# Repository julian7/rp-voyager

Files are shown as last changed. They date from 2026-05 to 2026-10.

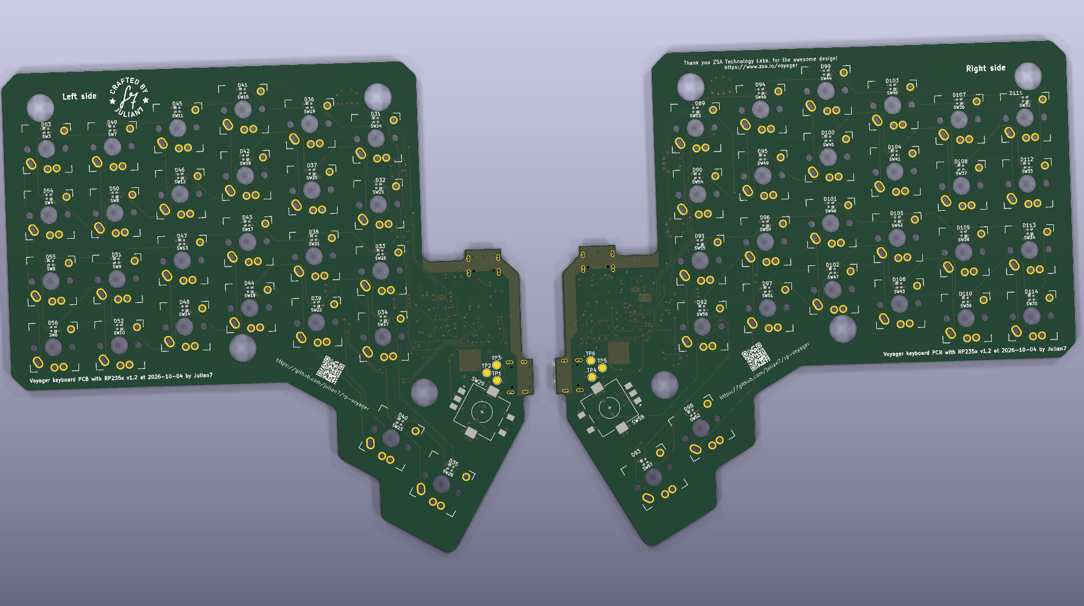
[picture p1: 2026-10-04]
docs/board-front.jpg

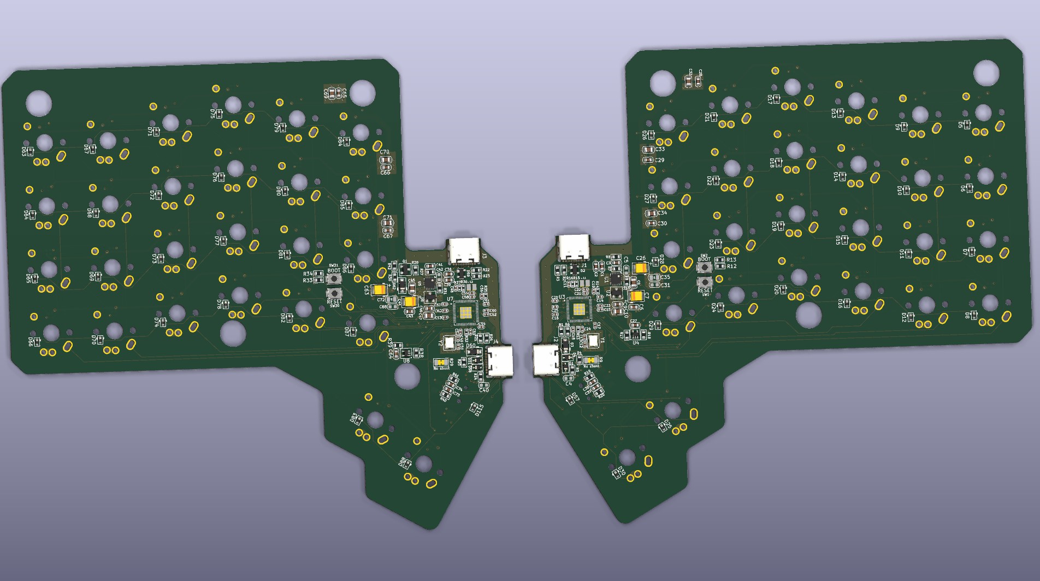
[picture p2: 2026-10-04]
docs/board-back.jpg

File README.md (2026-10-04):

# Voyager keyboard with RP2354A

This repository contains the necessary files for manufacturing of a split keyboard with on-board RP2354A microcontroller.

Features:

- On-board RP2354A MCU (2MB flash) for each side
- USB-C connection for power, firmware update, and a separate USB-C for UART connection between the halves
- RGB matrix under each key
- Gateron KS-33 / Kailh Choc v1 / Kailh Choc v2 low-profile keyswitches
- 1.2mm top plate (mainly planning for KS-33)

Non-features:

- Wireless functionality
- No tooling for mass production beyond common PCB houses and hobbyist CNC/3D print.

## What is Voyager?

Voyager is a minimal, split keyboard by [ZSA Technology Labs](https://www.zsa.io/), the same company who was behind the now discontinued Planck EZ.

The original Voyager is using an STM32 MCU, with RGB matrix. It has 52 keys, and 52 LEDs.

## Project status

Version v1.0 has been built, but the left side is not usable:

- ROW0-ROW3 are not connected to the MCU
- missing trace between CONN_TX test pad and the side USB recepticle's TX line

The right side can be put to work, with a single design flaw:

- The eFuse is always disabled. As a solution, put a 1 MΩ resistor (I've used a 0805 package, but probably a 0603 would be better) between pin 1 and pin 2 of Q1 MOSFET.

In general, LED silk screen markings were unreadable, and the ones I've purchased had different pin numbering. I've placed them by following the traces instead.

As a minor detail, SMD encoders' holes are a bit too tight, a 0.1mm clearance is added. Some silkscreen markings were adjusted for readability and visibility.

Version v1.1: only left side has been ordered, as there are no significant upgrades on the right side.

Version v1.2 (PCB only): hours after ordering the PCB I found that the keyboard layout is slightly different on the right side. Since I've ordered a new series of the left half, I've updated the design for the right one. A mechanical plate design now contains a v1-specific right plate.

## Can I copy it?

I don't recommend any usage at this point. Copyright-wise I retain all rights for now, probably opening up later. You can watch, you can learn, and you can laugh at my failures though.

The original design is originated by ZSA Technology Labs, Inc. I can't stop being gratituous enough for all the things they've done.

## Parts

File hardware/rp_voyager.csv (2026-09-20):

Reference | Qty | Value | DNP | Footprint | Distributor Link 1 | Distributor Link 2 | Distributor Link 3 | Description
R9,R29 | 2 | 0 | DNP | rp_voyager:R_1206_3216Metric_WireJumper |  |  |  | Resistor, small symbol
R10,R31 | 2 | 0 |  | PCM_Resistor_SMD_AKL:R_0603_1608Metric |  |  | https://www.hestore.hu/prod_10043634.html | Resistor, small symbol
C12,C13,C49,C50 | 4 | 15p |  | PCM_Capacitor_SMD_Handsoldering_AKL:C_0402_1005Metric |  |  |  | Unpolarized capacitor, small symbol
C5,C42 | 2 | 1n | DNP | PCM_Capacitor_SMD_Handsoldering_AKL:C_0603_1608Metric |  |  |  | Unpolarized capacitor, small symbol
C3,C41 | 2 | 10n |  | PCM_Capacitor_SMD_Handsoldering_AKL:C_0603_1608Metric |  |  | https://www.hestore.hu/prod_10027791.html | Unpolarized capacitor, small symbol
C4,C40 | 2 | 10n | DNP | PCM_Capacitor_SMD_Handsoldering_AKL:C_0603_1608Metric |  |  |  | Unpolarized capacitor, small symbol
C1,C6,C9,C27,C28,C29,C30,C36,C37,C38,C43,C46,C64,C65,C66,C67,C73,C74 | 18 | 100n |  | PCM_Capacitor_SMD_Handsoldering_AKL:C_0603_1608Metric |  |  | https://www.hestore.hu/prod_10033461.html | Unpolarized capacitor, small symbol
C11,C14,C15,C16,C17,C18,C20,C23,C25,C48,C51,C52,C53,C54,C55,C57,C60,C62 | 18 | 100n |  | PCM_Capacitor_SMD_Handsoldering_AKL:C_0402_1005Metric |  |  |  | Unpolarized capacitor, small symbol
C31,C68 | 2 | 100n | DNP | PCM_Capacitor_SMD_Handsoldering_AKL:C_0603_1608Metric |  |  |  | Unpolarized capacitor, small symbol
C19,C21,C22,C24,C56,C58,C59,C61 | 8 | 4.7u |  | PCM_Capacitor_SMD_Handsoldering_AKL:C_0402_1005Metric |  |  |  | Unpolarized capacitor, small symbol
C2,C39 | 2 | 10u |  | PCM_Capacitor_SMD_Handsoldering_AKL:C_0603_1608Metric |  |  | https://www.hestore.hu/prod_10043666.html | Unpolarized capacitor, small symbol
C8,C10,C32,C33,C34,C45,C47,C69,C70,C71 | 10 | 10u |  | PCM_Capacitor_SMD_Handsoldering_AKL:C_0805_2012Metric | https://hu.mouser.com/ProductDetail/KEMET/C0805C106M8RACAUTO7210?qs=HXFqYaX1Q2zcnWiZfdiXkQ%3D%3D |  |  | Poly
C35,C72 | 2 | 10u | DNP | PCM_Capacitor_SMD_Handsoldering_AKL:C_0805_2012Metric |  |  |  | Poly
C7,C26,C44,C63 | 4 | 220u |  | PCM_Capacitor_SMD_Handsoldering_AKL:C_1210_3225Metric | https://hu.mouser.com/ProductDetail/KYOCERA-AVX/TCJB227M006R0070 |  |  | 220uF 6.3V Polymer
R17,R38 | 2 | 22 |  | PCM_Resistor_SMD_AKL:R_0603_1608Metric |  |  | https://www.hestore.hu/prod_10023927.html | Resistor, small symbol
R15,R16,R36,R37 | 4 | 27 |  | PCM_Resistor_SMD_AKL:R_0402_1005Metric | https://hu.mouser.com/ProductDetail/YAGEO/RC0402FR-0727RL?qs=UOUeRUa%252B8Wlb37UyFHw9Bw%3D%3D |  |  | Resistor, small symbol
R14,R35 | 2 | 33 |  | PCM_Resistor_SMD_AKL:R_0402_1005Metric | https://hu.mouser.com/ProductDetail/YAGEO/RC0402FR-7D33RL |  |  | Resistor, small symbol
R18,R39 | 2 | 47 |  | PCM_Resistor_SMD_AKL:R_0603_1608Metric |  |  | https://www.hestore.hu/prod_10049205.html | Resistor, small symbol
R1,R6,R21,R26 | 4 | 220 |  | PCM_Resistor_SMD_AKL:R_0603_1608Metric |  |  | https://www.hestore.hu/prod_10036836.html | Resistor, small symbol
R11,R32 | 2 | 1k |  | PCM_Resistor_SMD_AKL:R_0402_1005Metric |  |  | https://www.hestore.hu/prod_10030528.html | Resistor, small symbol
R12,R13,R33,R34 | 4 | 1k |  | PCM_Resistor_SMD_AKL:R_0603_1608Metric |  |  | https://www.hestore.hu/prod_10049434.html | Resistor, small symbol
R2,R3,R4,R5,R22,R23,R24,R25 | 8 | 5.1k |  | PCM_Resistor_SMD_AKL:R_0603_1608Metric |  |  | https://www.hestore.hu/prod_10036539.html | Resistor, small symbol
R7,R19,R20,R27,R40,R41 | 6 | 10k |  | PCM_Resistor_SMD_AKL:R_0603_1608Metric |  |  | https://www.hestore.hu/prod_10023910.html | Resistor, small symbol
R8,R28,R30 | 3 | 100k |  | PCM_Resistor_SMD_AKL:R_0603_1608Metric |  |  | https://www.hestore.hu/prod_10043366.html | Resistor, small symbol
Y1,Y2 | 2 | 12MHz |  | PCM_Crystal_AKL:Crystal_SMD_3225-4Pin_3.2x2.5mm_HandSoldering | https://hu.mouser.com/ProductDetail/ABRACON/ABM8-272-T3?qs=QpmGXVUTftEj6miOiJBMxQ%3D%3D |  |  | ABM8-272-T3
D5,D6,D7,D8,D9,D10,D11,D12,D13,D14,D15,D16,D17,D18,D19,D20,D21,D22,D23,D24,D25,D26,D27,D28,D29,D30,D57,D63,D64,D65,D66,D67,D68,D69,D70,D71,D72,D73,D74,D75,D76,D77,D78,D79,D80,D81,D82,D83,D84,D85,D86,D87,D88,D115 | 54 | 1N4148WT |  | PCM_Diode_SMD_AKL:D_SOD-523 |  |  |  | Diode, small symbol
Q1 | 1 | 2N7002 |  | PCM_Package_TO_SOT_SMD_AKL:SOT-23 | https://hu.mouser.com/ProductDetail/Panjit/2N7002K_R1_00001?qs=sPbYRqrBIVmx5ZVZGJfwpA%3D%3D |  |  | SOT-23 N-MOSFET enchancement mode transistor, 60V, 380mA, 370mW, Alternate KiCAD Library
U4,U8 | 2 | 74HCT1G125GW |  | PCM_Package_TO_SOT_SMD_AKL:SOT-353_SC-70-5 | https://hu.mouser.com/ProductDetail/Nexperia/74HCT1G125GW125?qs=P62ublwmbi9fxWhuHktl8w%3D%3D |  |  | Single Buffer Gate Tri-State, Low-Voltage CMOS
L1,L2 | 2 | AOTA-B201610S3R3-101-T |  | rp_voyager:INDC2016X100N | https://hu.mouser.com/ProductDetail/815-AB201610S3R3101T |  |  | Power Inductors - SMD IND 3.3uH
U2,U6 | 2 | AP2125N-3.3TRG1 |  | PCM_Package_TO_SOT_SMD_AKL:SOT-23 | https://hu.mouser.com/ProductDetail/Diodes-Incorporated/AP2125N-3.3TRG1?qs=x6A8l6qLYDCwcNnV9UPDXg%3D%3D |  |  | SOT-23 3.3V 300mA low dropout voltage regulator, Alternate KiCad Library
D62 | 1 | B0520LW-7-F |  | PCM_Diode_SMD_Handsoldering_AKL:D_SOD-123 | https://hu.mouser.com/ProductDetail/Diodes-Incorporated/B0520LW-7-F?qs=ohlXZ7HLwzhBk0UMEtqL4A%3D%3D
SW2,SW31 | 2 | BOOTSEL |  | Button_Switch_SMD:SW_Push_SPST_NO_Alps_SKRK |  |  |  | Push button switch, generic, two pins
D1,D4,D58,D61 | 4 | DESD5V0U1BA-7 |  | PCM_Diode_SMD_Handsoldering_AKL:D_SOD-323_TVS | https://hu.mouser.com/ProductDetail/Diodes-Incorporated/DESD5V0U1BA-7?qs=wtVJq%252Be05r98RUWcs2LyvQ%3D%3D |  |  | Bidirectional TVS Diode, Generic symbol, Alternate KiCAD Library
TP3,TP6 | 2 | I2C 5V |  | TestPoint:TestPoint_Pad_D2.0mm |  |  |  | test point
J1,J3 | 2 | INPUT USB |  | Connector_USB:USB_C_Receptacle_GCT_USB4105-xx-A_16P_TopMnt_Horizontal |  |  |  | USB 2.0-only 14P Type-C Receptacle connector
SW3,SW4,SW5,SW6,SW7,SW8,SW9,SW10,SW11,SW12,SW13,SW14,SW15,SW16,SW17,SW18,SW19,SW20,SW21,SW22,SW23,SW24,SW25,SW26,SW27,SW32,SW33,SW34,SW35,SW36,SW37,SW38,SW39,SW40,SW41,SW42,SW43,SW44,SW45,SW46,SW47,SW48,SW49,SW50,SW51,SW52,SW53,SW54,SW55,SW56 | 50 | Key |  | rp_voyager:Gateron-KS33-Solderable-1U |  |  |  | Push button switch, normally open, two pins, 45Ã Â° tilted
SW28,SW57 | 2 | Key |  | rp_voyager:Gateron-KS33-Solderable-1x1.5U |  |  |  | Push button switch, normally open, two pins, 45Ã Â° tilted
D2,D59 | 2 | PRTR5V0U2X |  | Package_TO_SOT_SMD:SOT-143 | https://hu.mouser.com/ProductDetail/Nexperia/PRTR5V0U2X215?qs=LOCUfHb8d9sDkgY4cRj8Lw%3D%3D |  |  | Ultra low capacitance double rail-to-rail ESD protection diode, SOT-143
SW1,SW30 | 2 | RESET |  | Button_Switch_SMD:SW_Push_SPST_NO_Alps_SKRK |  |  |  | Push button switch, generic, two pins
SW29,SW58 | 2 | RotaryEncoder_Switch_MP |  | rp_voyager:RotaryEncoder_Alps_EC11S-Switch_Vertical_H9mm |  |  |  | Rotary encoder, dual channel, incremental quadrate outputs, with switch and MP Pin
U3,U7 | 2 | RP2354A |  | Package_DFN_QFN:QFN-60-1EP_7x7mm_P0.4mm_EP3.4x3.4mm |  |  |  | A microcontroller by Raspberry Pi, dual CPU architecture (ARM Cortex-M33 / RISC-V Hazard3), 150MHz, 2MB flash, 520KB SRAM, 12 PIO state machines, VQFN-60
D31,D32,D33,D34,D35,D36,D37,D38,D39,D40,D41,D42,D43,D44,D45,D46,D47,D48,D49,D50,D51,D52,D53,D54,D55,D56,D89,D90,D91,D92,D93,D94,D95,D96,D97,D98,D99,D100,D101,D102,D103,D104,D105,D106,D107,D108,D109,D110,D111,D112,D113,D114 | 52 | SK6812 EC20 |  | rp_voyager:LED_SK6812_EC20_2x2mm |  |  |  | RGB LED with integrated controller, 2.0 x 2.0 mm, 12 mA
D3,D60 | 2 | SZSMF5.0AT1G |  | PCM_Diode_SMD_Handsoldering_AKL:D_SOD-123_Zener | https://hu.mouser.com/ProductDetail/Littelfuse/SZSMF5.0AT1G?qs=sK5eIuwOod5l2VwwT9yiGQ%3D%3D |  |  | Unidirectional TVS diode, Generic symbol, Alternate KiCAD Library
U1,U5 | 2 | TPS259261 |  | Package_SON:VSON-10-1EP_3x3mm_P0.5mm_EP1.65x2.4mm_ThermalVias | https://hu.mouser.com/ProductDetail/Texas-Instruments/TPS259261DRCR?qs=rBWM4%252BvDhIfYkNEYPOLMtQ%3D%3D | https://www.digikey.hu/hu/products/detail/texas-instruments/tps259261drcr/5481852 |  | 5V/12V eFuse Protection Switch (VSON-10)
J2,J4 | 2 | UART USB |  | Connector_USB:USB_C_Receptacle_GCT_USB4105-xx-A_16P_TopMnt_Horizontal |  |  |  | USB 2.0-only 14P Type-C Receptacle connector
TP2,TP5 | 2 | UART_RX |  | TestPoint:TestPoint_Pad_D2.0mm |  |  |  | test point
TP1,TP4 | 2 | UART_TX |  | TestPoint:TestPoint_Pad_D2.0mm |  |  |  | test point

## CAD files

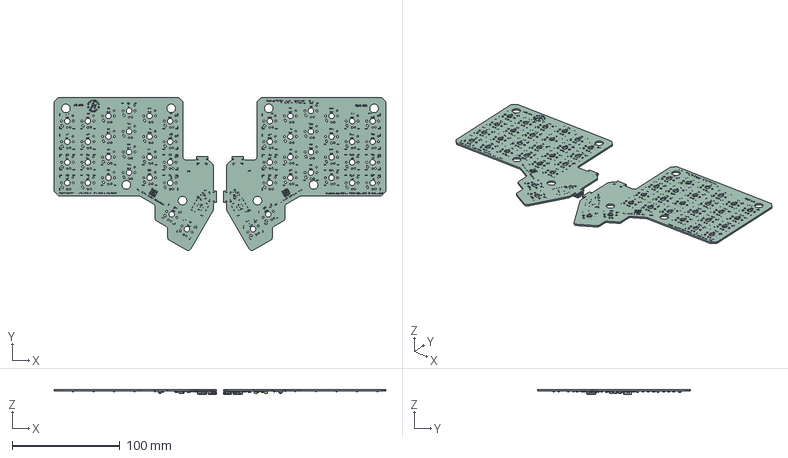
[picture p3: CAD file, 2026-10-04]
mechanical/board_v12.step
307.5 x 141.7 x 4.98 mm
C_0402_1005Metric x 30
D_SOD-123 x 3
D_SOD_523 x 54
D_SOD-323 x 4
CP_EIA_3528_21_Kemet_B x 4
R_0603_1608Metric x 32
C_0603_1608Metric x 28
SOT-23 x 3
R_0402_1005Metric x 8
SOT-353_SC-70-5 x 2
C_0805_2012Metric x 12
SW_Push_SPST_NO_Alps_SKRK x 4
R_1206_3216Metric x 2
USB_C_Receptacle_16P_TopMnt_Horizontal_GCT_USB4105-xx-A x 4
SOT-143 x 2
VSON_10_1EP_3x3mm_Pitch05mm_ThermalPad x 2
Crystal_SMD_Abracon_ABM8G-4Pin_3.2x2.5mm x 2
rp_voyager_silkscreen x 2
rp_voyager_PCB_1
rp_voyager_PCB_2

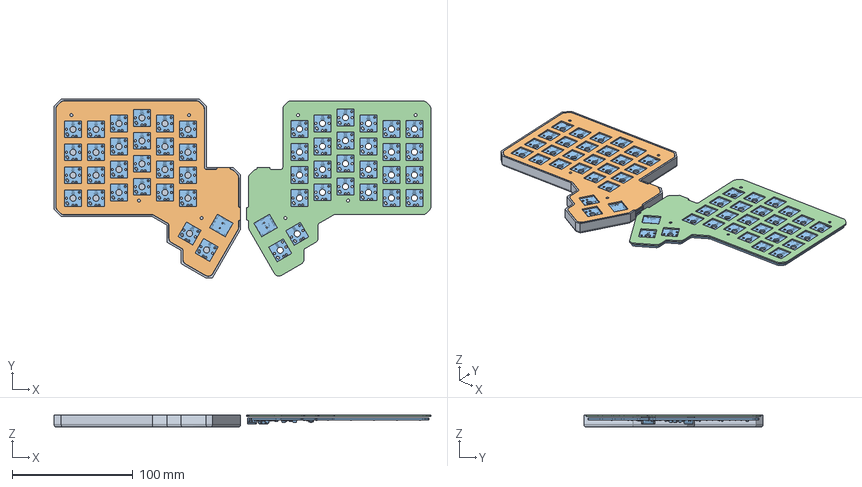
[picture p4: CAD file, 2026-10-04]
mechanical/rp-voyager.FCStd
312.6 x 148.7 x 10.1 mm
tray
plate
board_v1.1
plate-right-v1

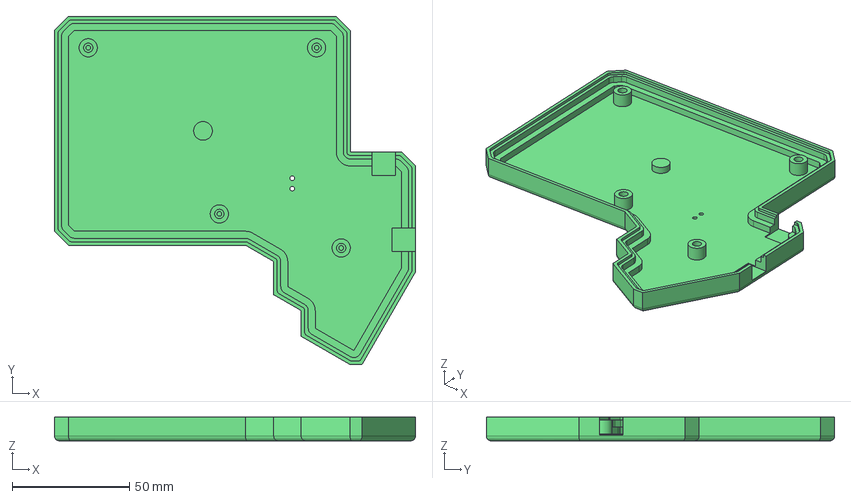
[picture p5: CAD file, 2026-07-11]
mechanical/rp-voyager-tray.step
154.1 x 148.7 x 10.1 mm

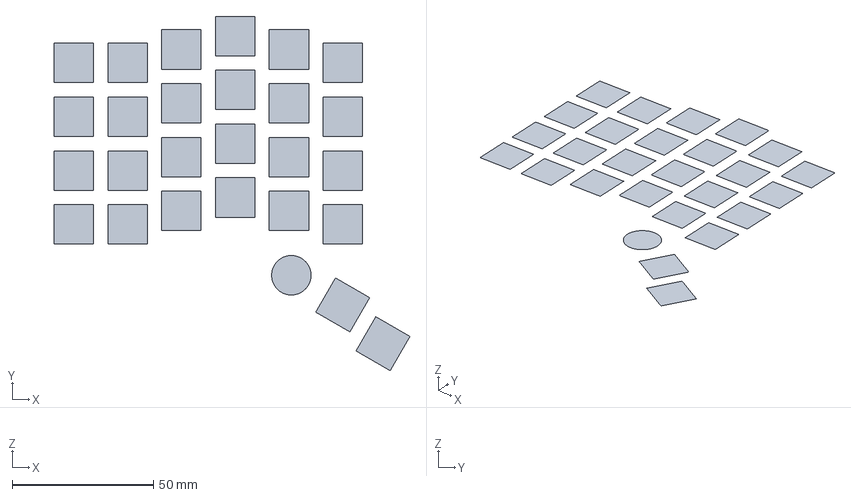
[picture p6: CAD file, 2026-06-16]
mechanical/layout.FCStd
126.0 x 125.5 x 0 mm

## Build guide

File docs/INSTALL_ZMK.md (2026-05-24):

# ZMK firmware for RP-Voyager

## Install native ZMK toolchain

```shell
brew install uv cmake ninja gperf python3 python-tk ccache qemu dtc libmagic wget openocd
uv tool install west
git clone https://github.com/zmkfirmware/zmk.git ~/src/zmk
cd zmk
uv init --bare
uv add west pip
uv run west init -l app/
uv run west update
uv run west zephyr-export
uv run west packages pip --install
uv run west sdk install -t arm-zephyr-eabi
```

## Specifics

The previous snippet assumes MacOS with Homebrew. Follow [Native local toolchain setup](https://zmk.dev/docs/development/local-toolchain/setup/native) guide for your operating system.

It also depends on `uv` so that the environment can be localized into `~/src/zmk`. You'll have to initiate builds from that directory.

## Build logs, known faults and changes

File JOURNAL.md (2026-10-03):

# Journal

The local supplier doesn't have everything in stock, so I ordered the main components from Mouser. I've ordered some of the components from Aliexpress.

I've made the first release, tagged as v1.0. I've ordered 5 prototype boards from JLCPCB, with stencils.  All the components arrived. The stencil made the PCB ordering way harder, as it was held back at customs for a week, as it was missing sanction declaration.

I've placed the bottom components of the left side, with some findings:

- The bulk cap (220 µF) has a 6.3V rating, which might be a bit problematic on the 5V rail. I've replaced that with a 10V-rated one, but I decided it will still do some good work on the LED circuit.
- Markings for the poly bulk cap is unipolar, but it is a polarized capacitor. It also caused a short, as it was placed anode side to GND.
- The crystal is taking a huge chunk of real estate, that could be smaller.
- Minor nuissance, ROW0-ROW3 are not connected to the MCU, leaving the majority of the keys unusable on the left side.
- There is a missing trace between CONN_TX test pad and the side USB recepticle's TX line in the design. For some reason, they are connected on the board I've received.

I now continue with some LEDs and making a right side, so that I can find more issues before placing a second order for PCBs.

---

Sep 30

I've built a right side, only bottom side. The board has some issues with the eFuse's EN signal. The board takes 0.037A if Q1 is off the board, that's a normal power consumption with no LEDs. Probably, Q1 gate needs a 1M pulldown resistor.

I want to test all three power scenarios on the right side: main only, side only, both. I'll use the PSU on main for the third scenario, I should measure 0A.

---

Oct 2

The right half started working well once I've installed a 1MΩ resistor between Q1's pin 1 and 2. The eFuse is disabled consistently when power also comes from UART USB.

I've installed a few LEDs, but they don't seem to be driven. The left side had a LED lighting bright blue for a moment, but it lasted only a second. I'll have to go back to the backlight once the more fundamental questions are solved.

I've updated the filler GPIO layouts, so that they are correctly connected. The keyboard matrix had some surprises too, as the right side's colums have been wired right to left. Apart from that, the right side is functioning well.

~~Apparently, sometimes the LEDs are working "somewhat", probably the first LEDs are broken but not completely dead.~~

Apparently, only one LED is burnt, the others had soldering issues.

---

Oct 3

Finished building the right side. All LEDs, all hotswap sockets, and the encoder works well through the UART connection from the left side.

At the same time, the first LED works on the left side, so we can conclude that only the left side PCB needs an update, the right one can be fixed with a 0603 resistor soldered on Q1's pins 1-2.

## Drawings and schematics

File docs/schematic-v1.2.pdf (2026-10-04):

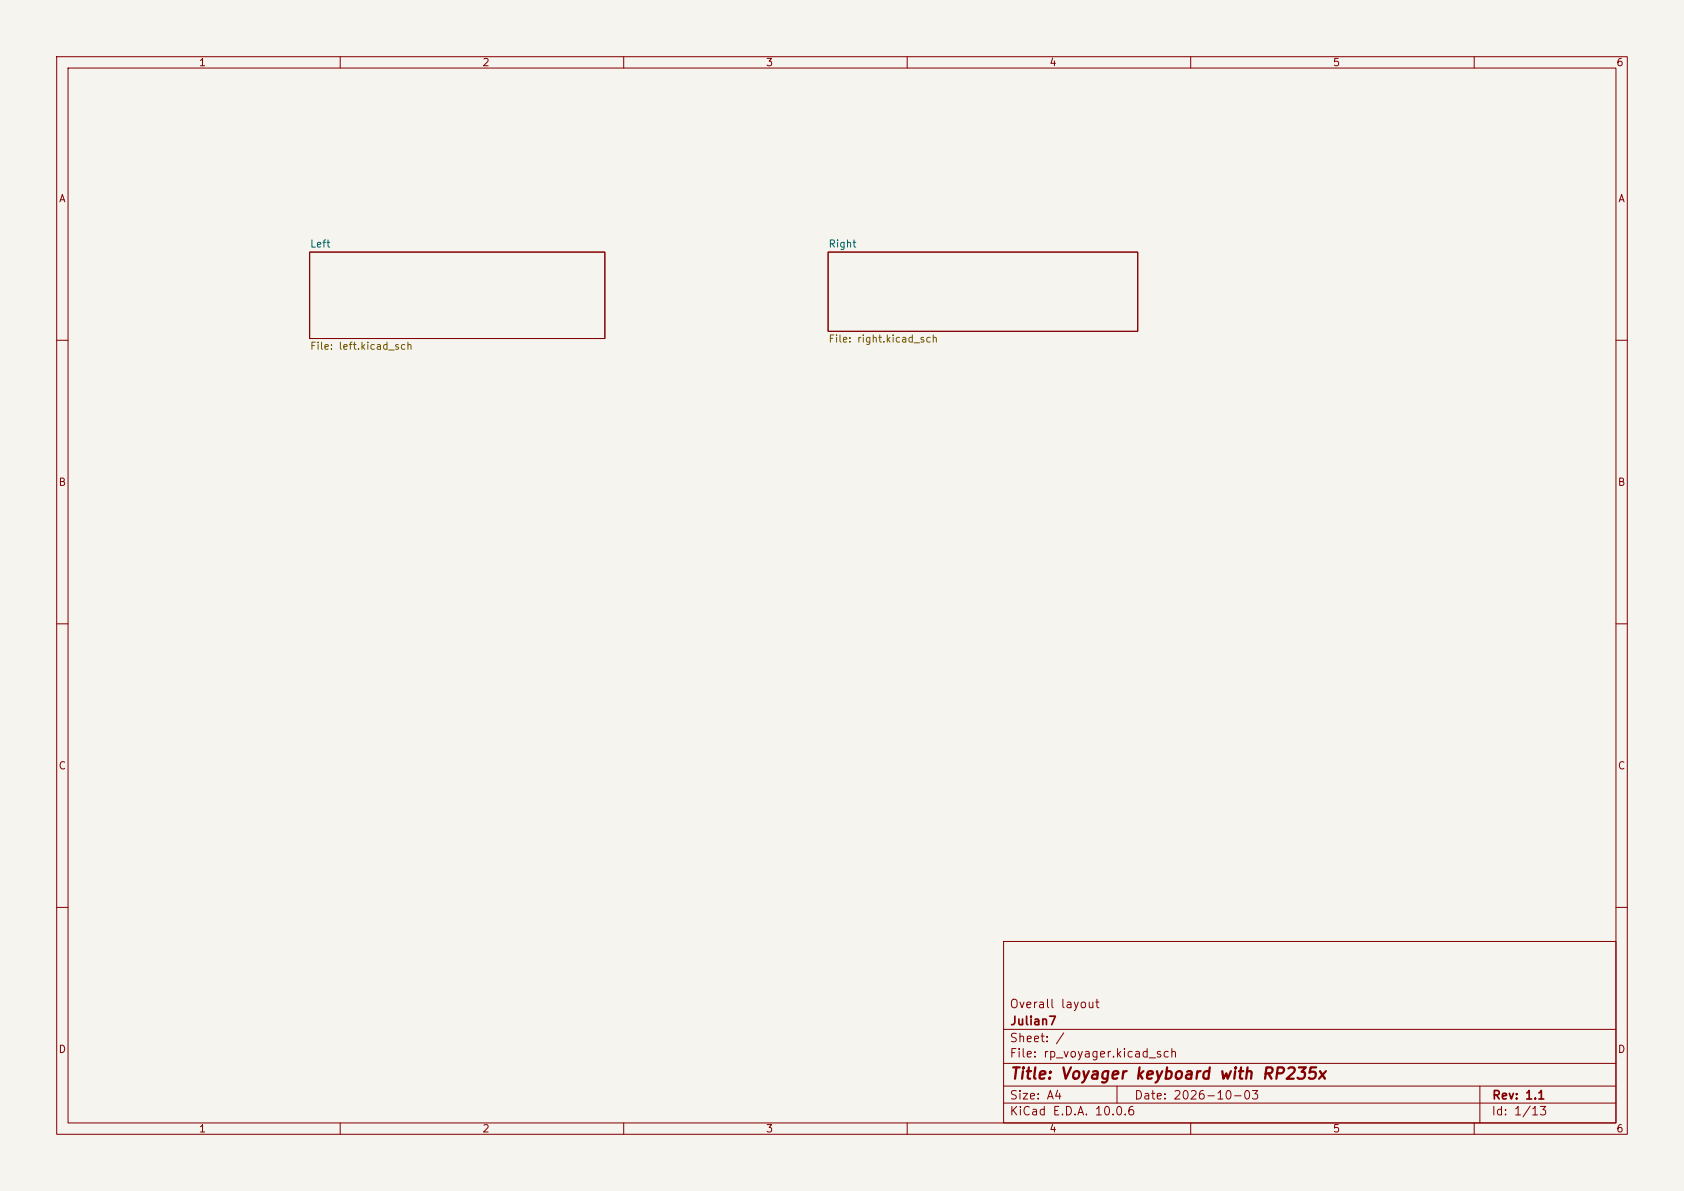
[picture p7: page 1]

Size: A4 | Rev: 1.1
KiCad E.D.A. 10.0.6 | Id: 1/13

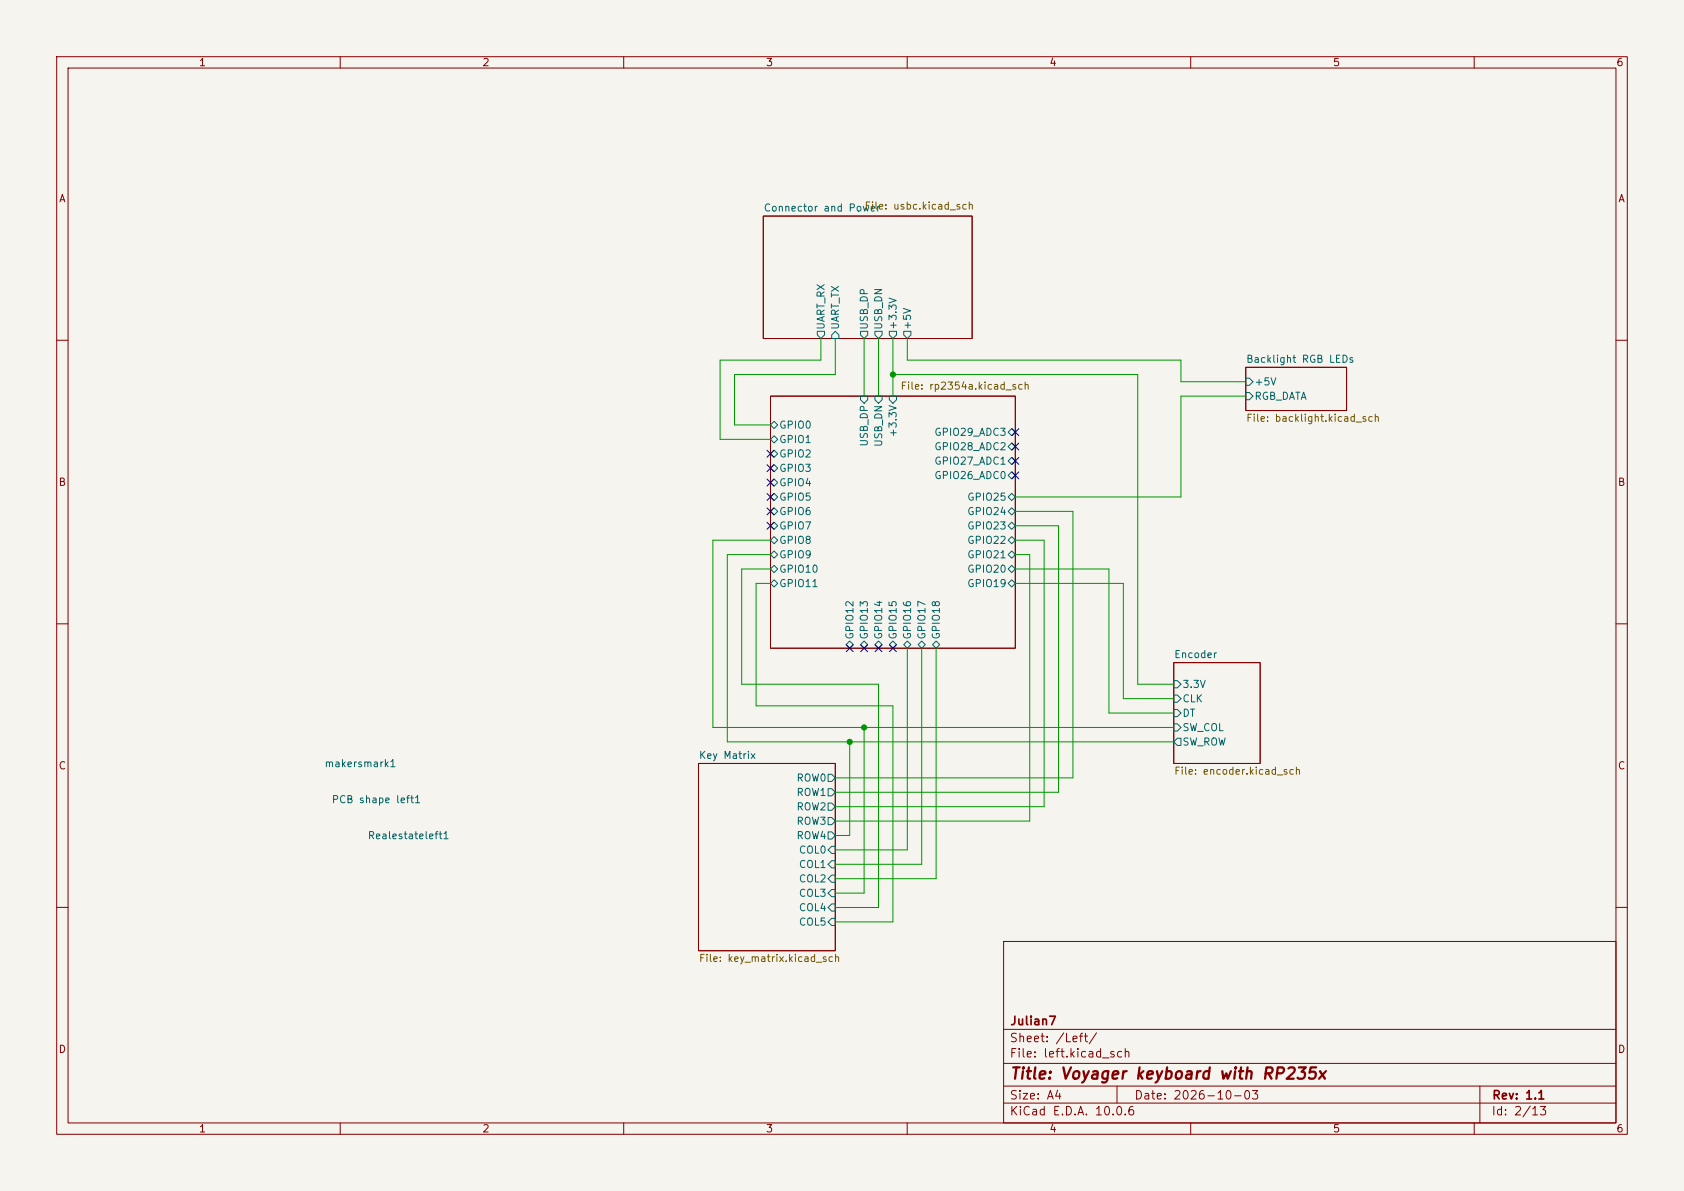
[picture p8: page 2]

Julian7
Sheet: /Left/
File: left.kicad_sch
Title: Voyager keyboard with RP235x

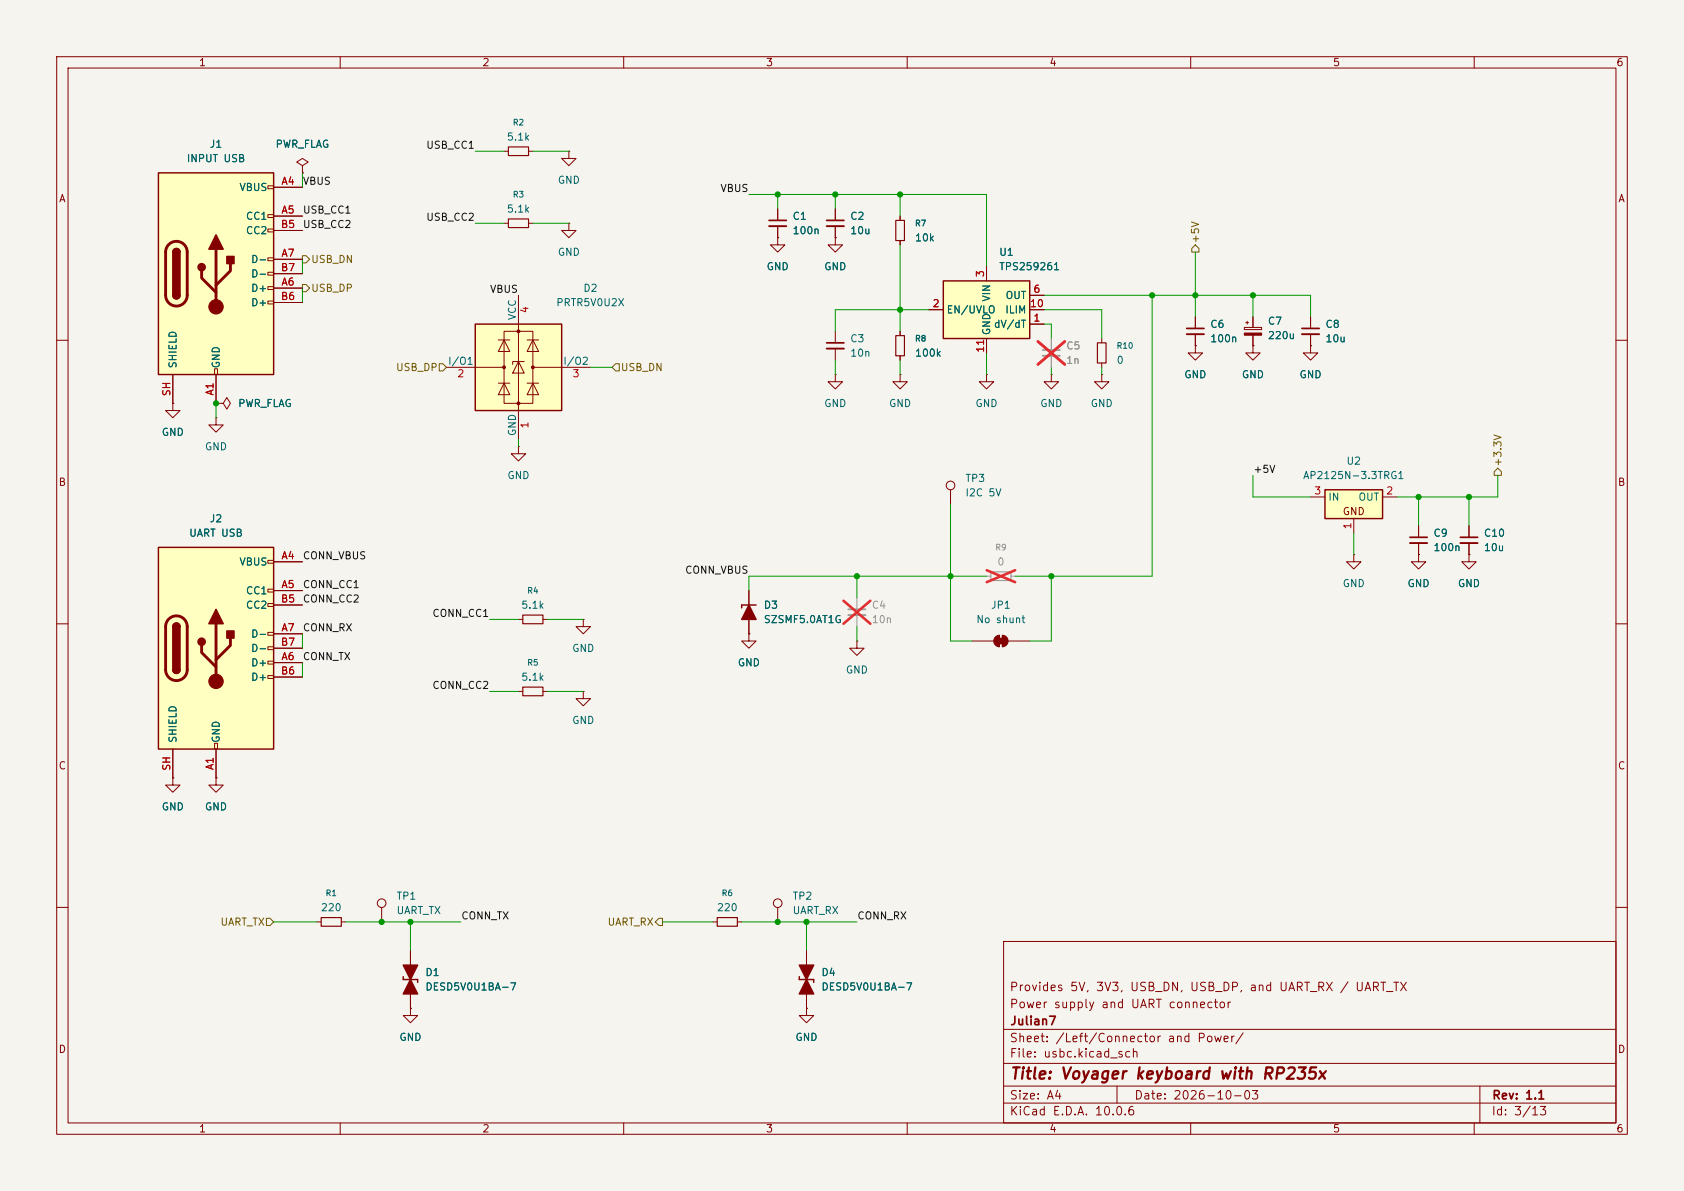
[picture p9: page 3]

Provides 5V, 3V3, USB_DN, USB_DP, and UART_RX / UART_TX
Power supply and UART connector
Julian7
Sheet: /Left/Connector and Power/
File: usbc.kicad_sch
Title: Voyager keyboard with RP235x

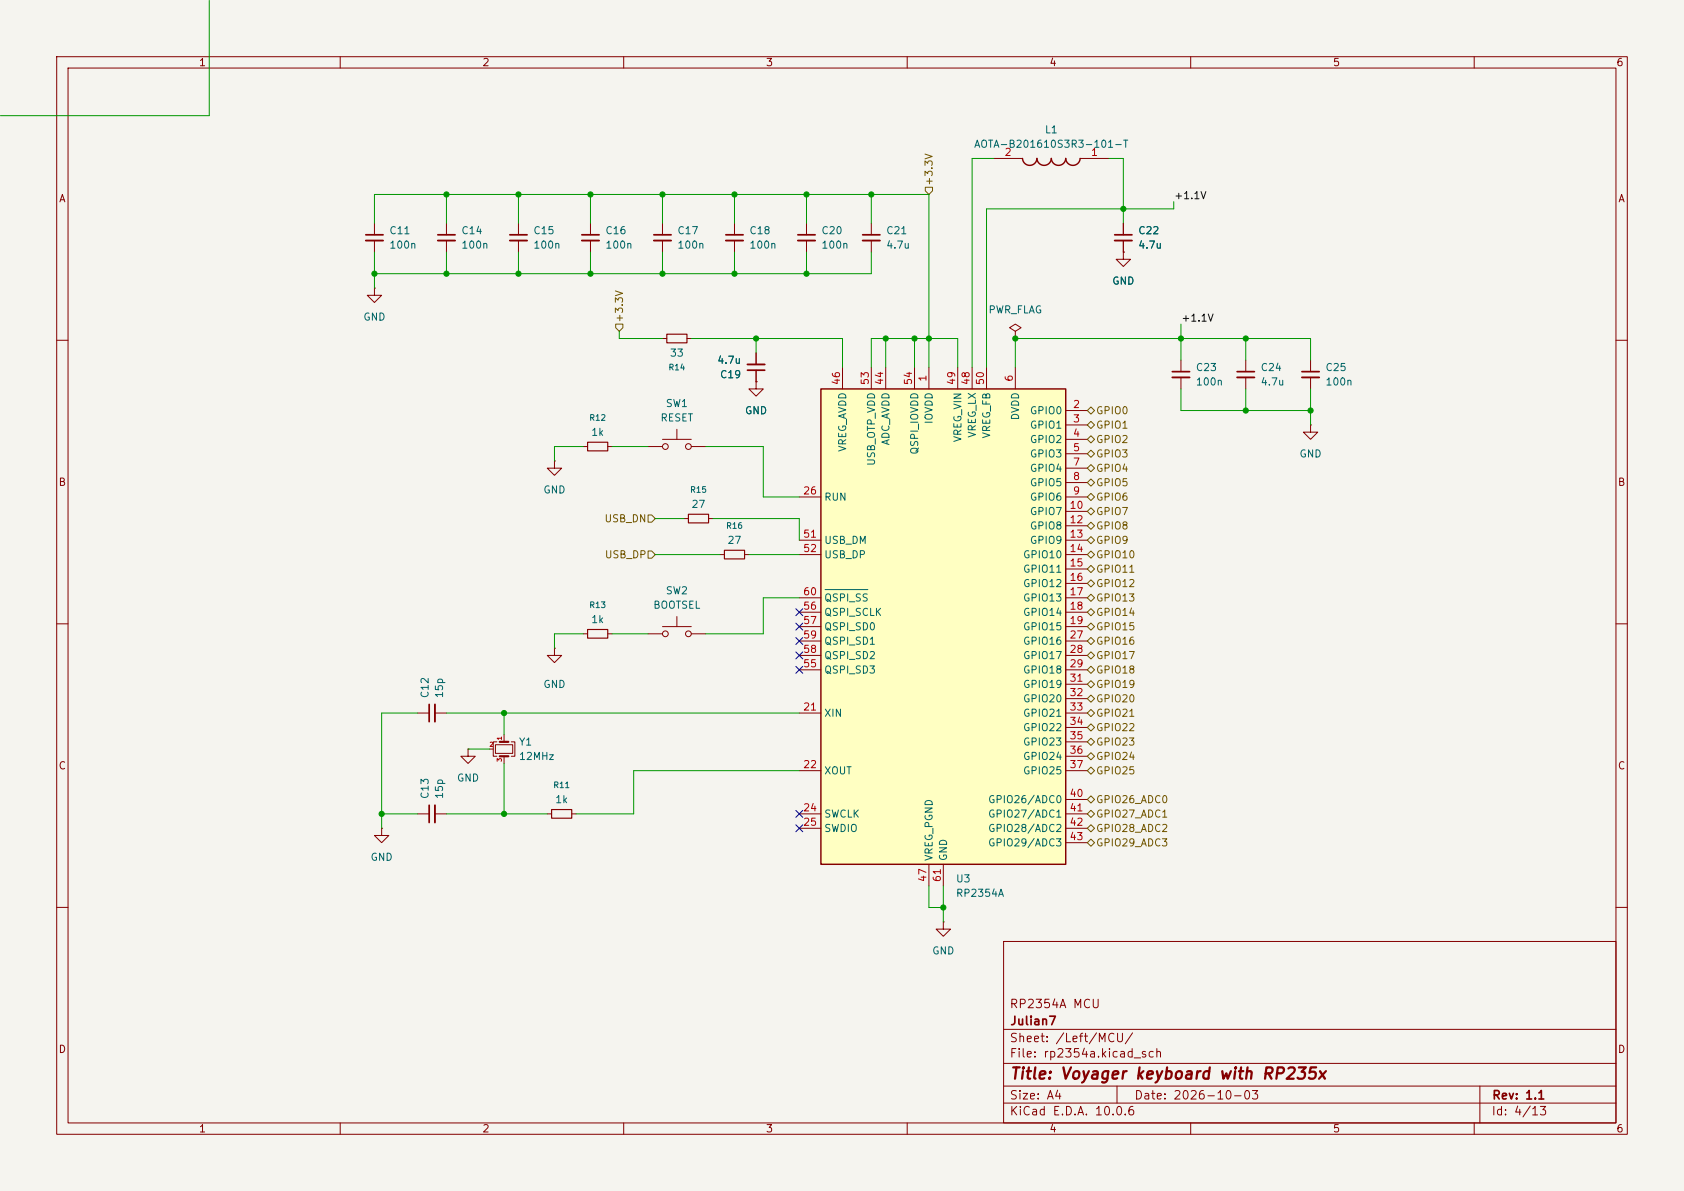
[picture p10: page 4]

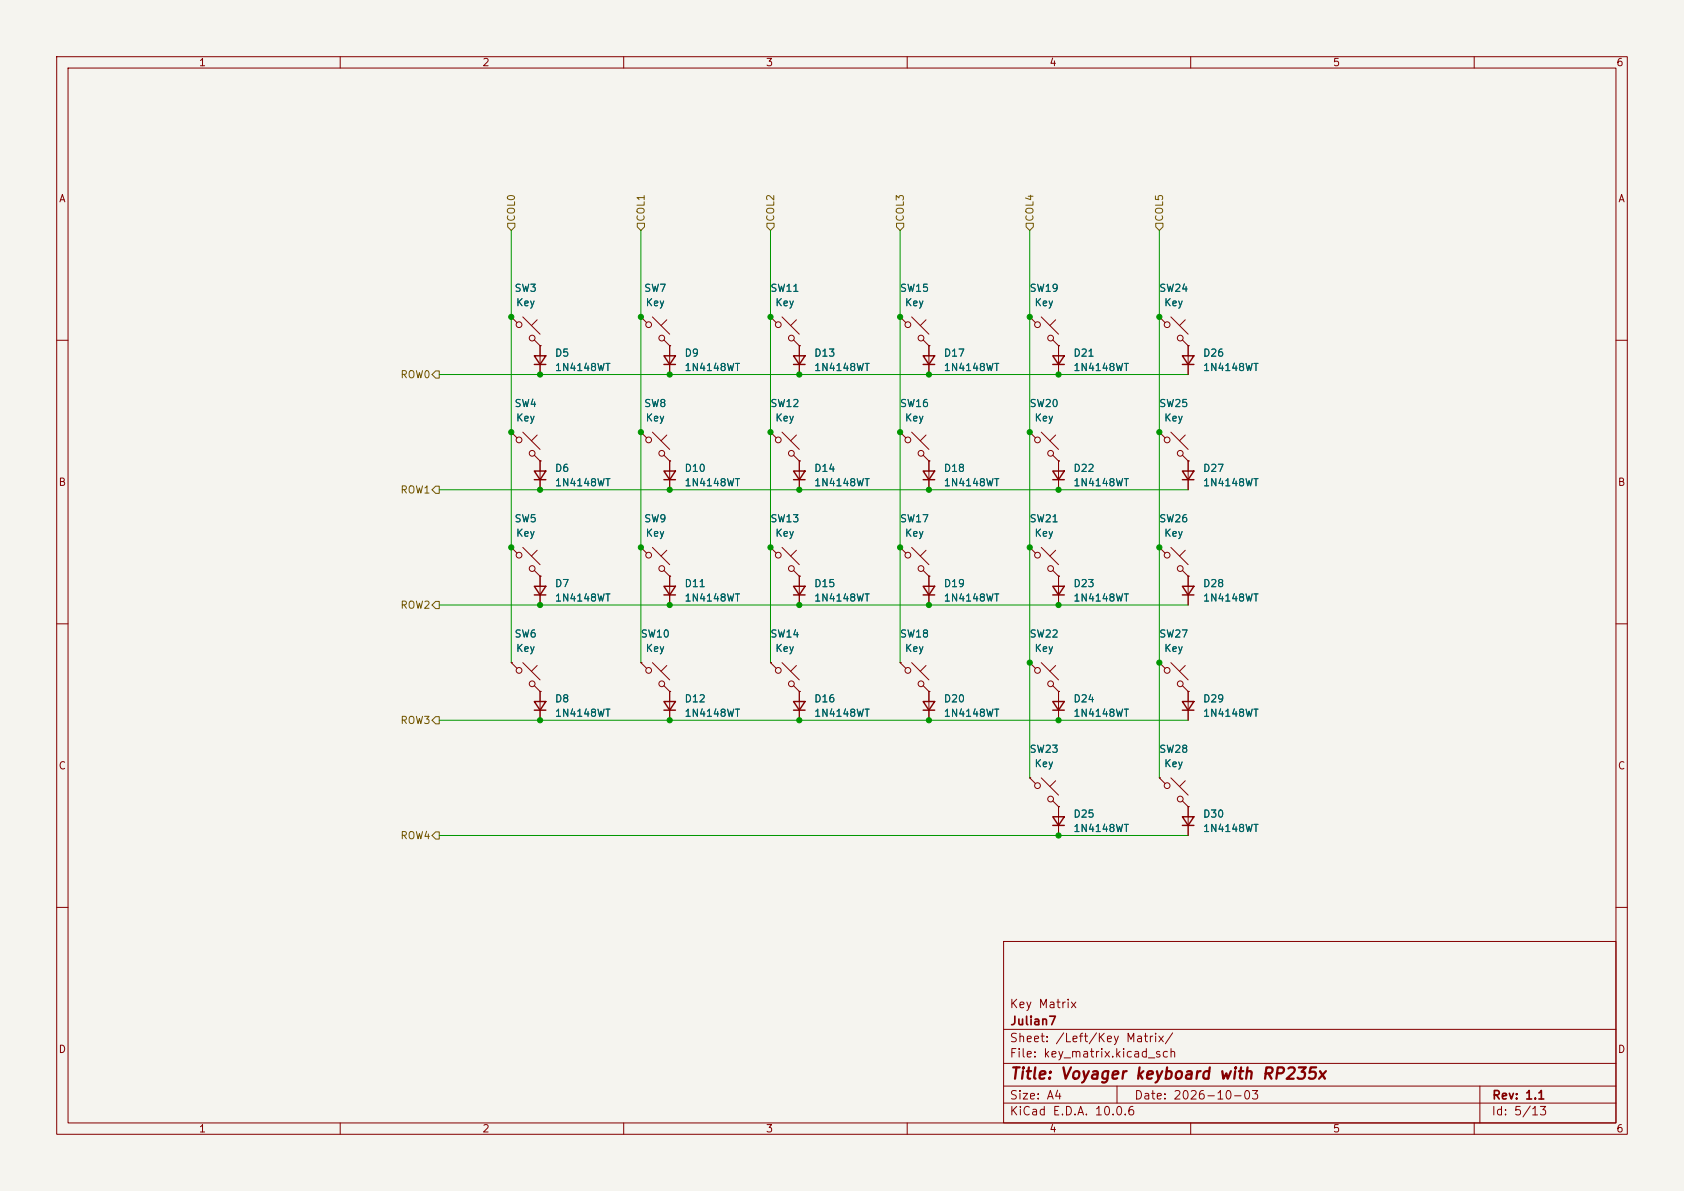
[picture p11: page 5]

Key Matrix
Julian7
Sheet: /Left/Key Matrix/
File: key_matrix.kicad_sch
Title: Voyager keyboard with RP235x

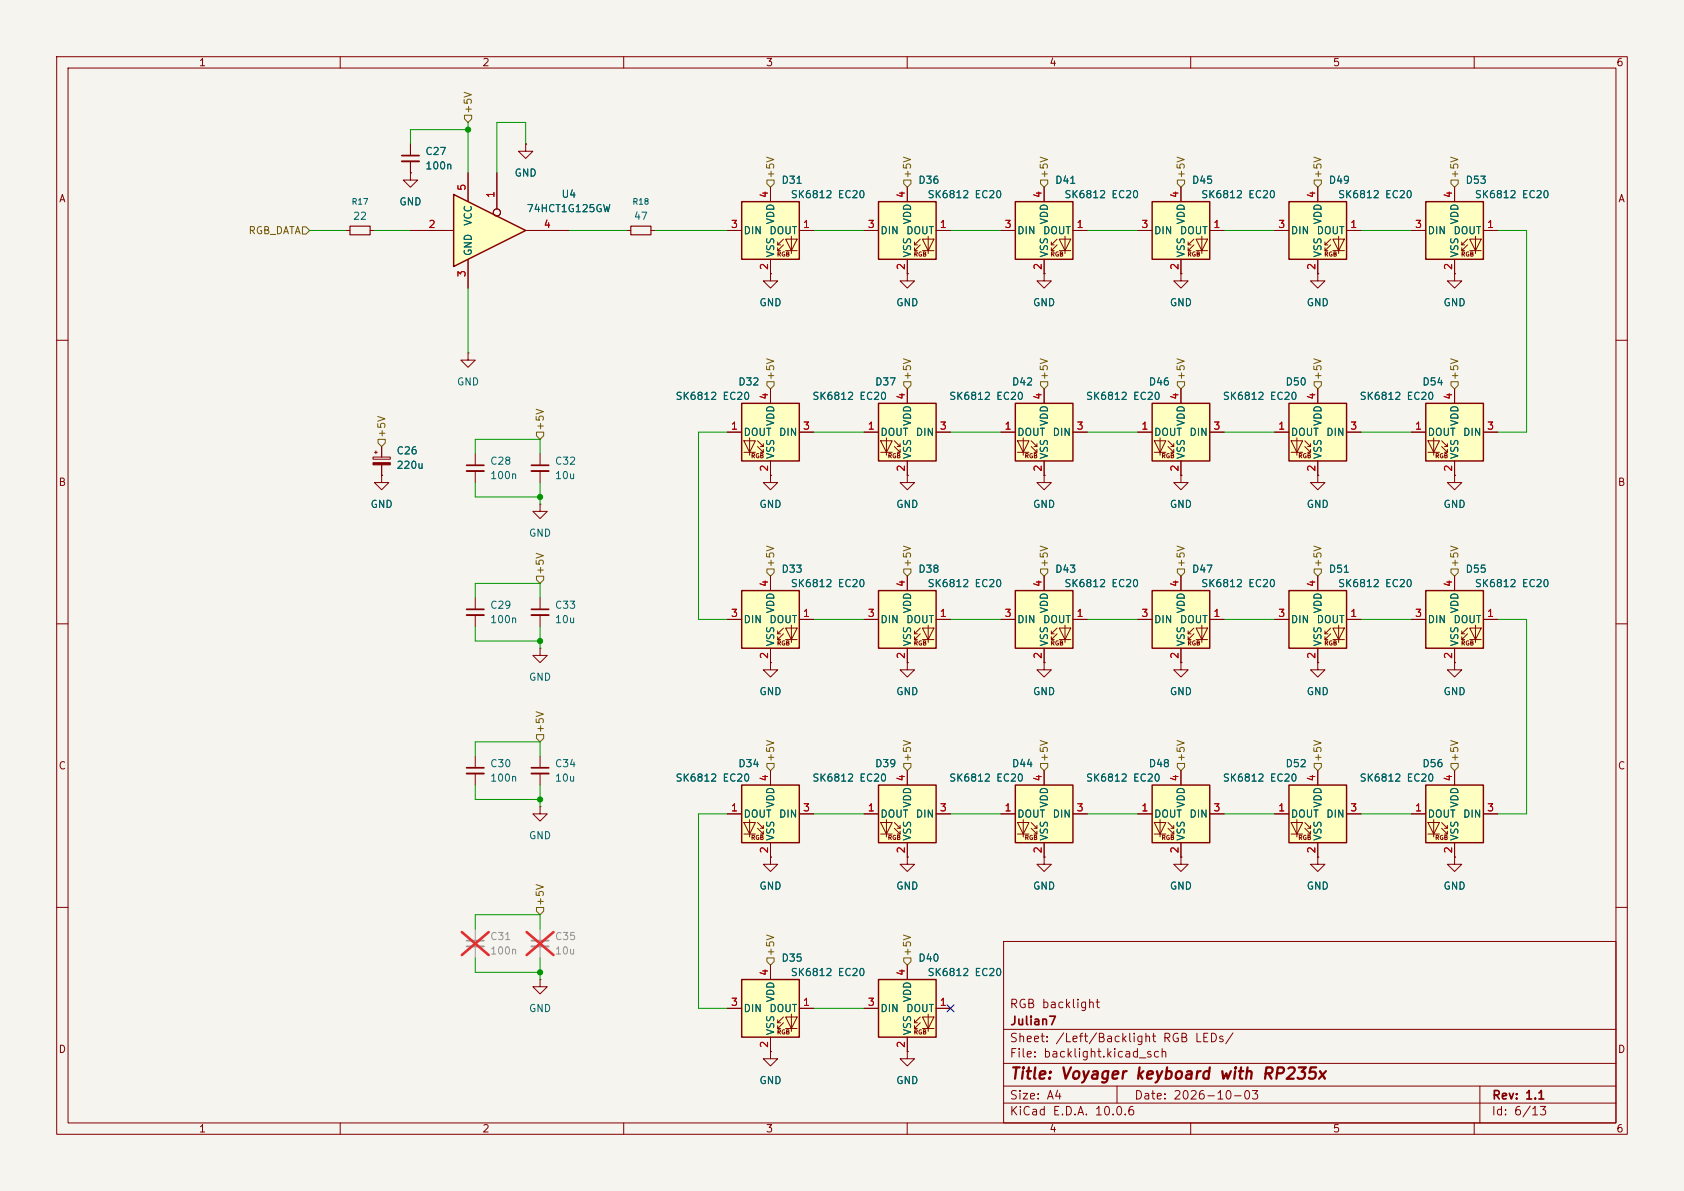
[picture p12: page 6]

Julian7
Sheet: /Left/Backlight RGB LEDs/
File: backlight.kicad_sch
Title: Voyager keyboard with RP235x

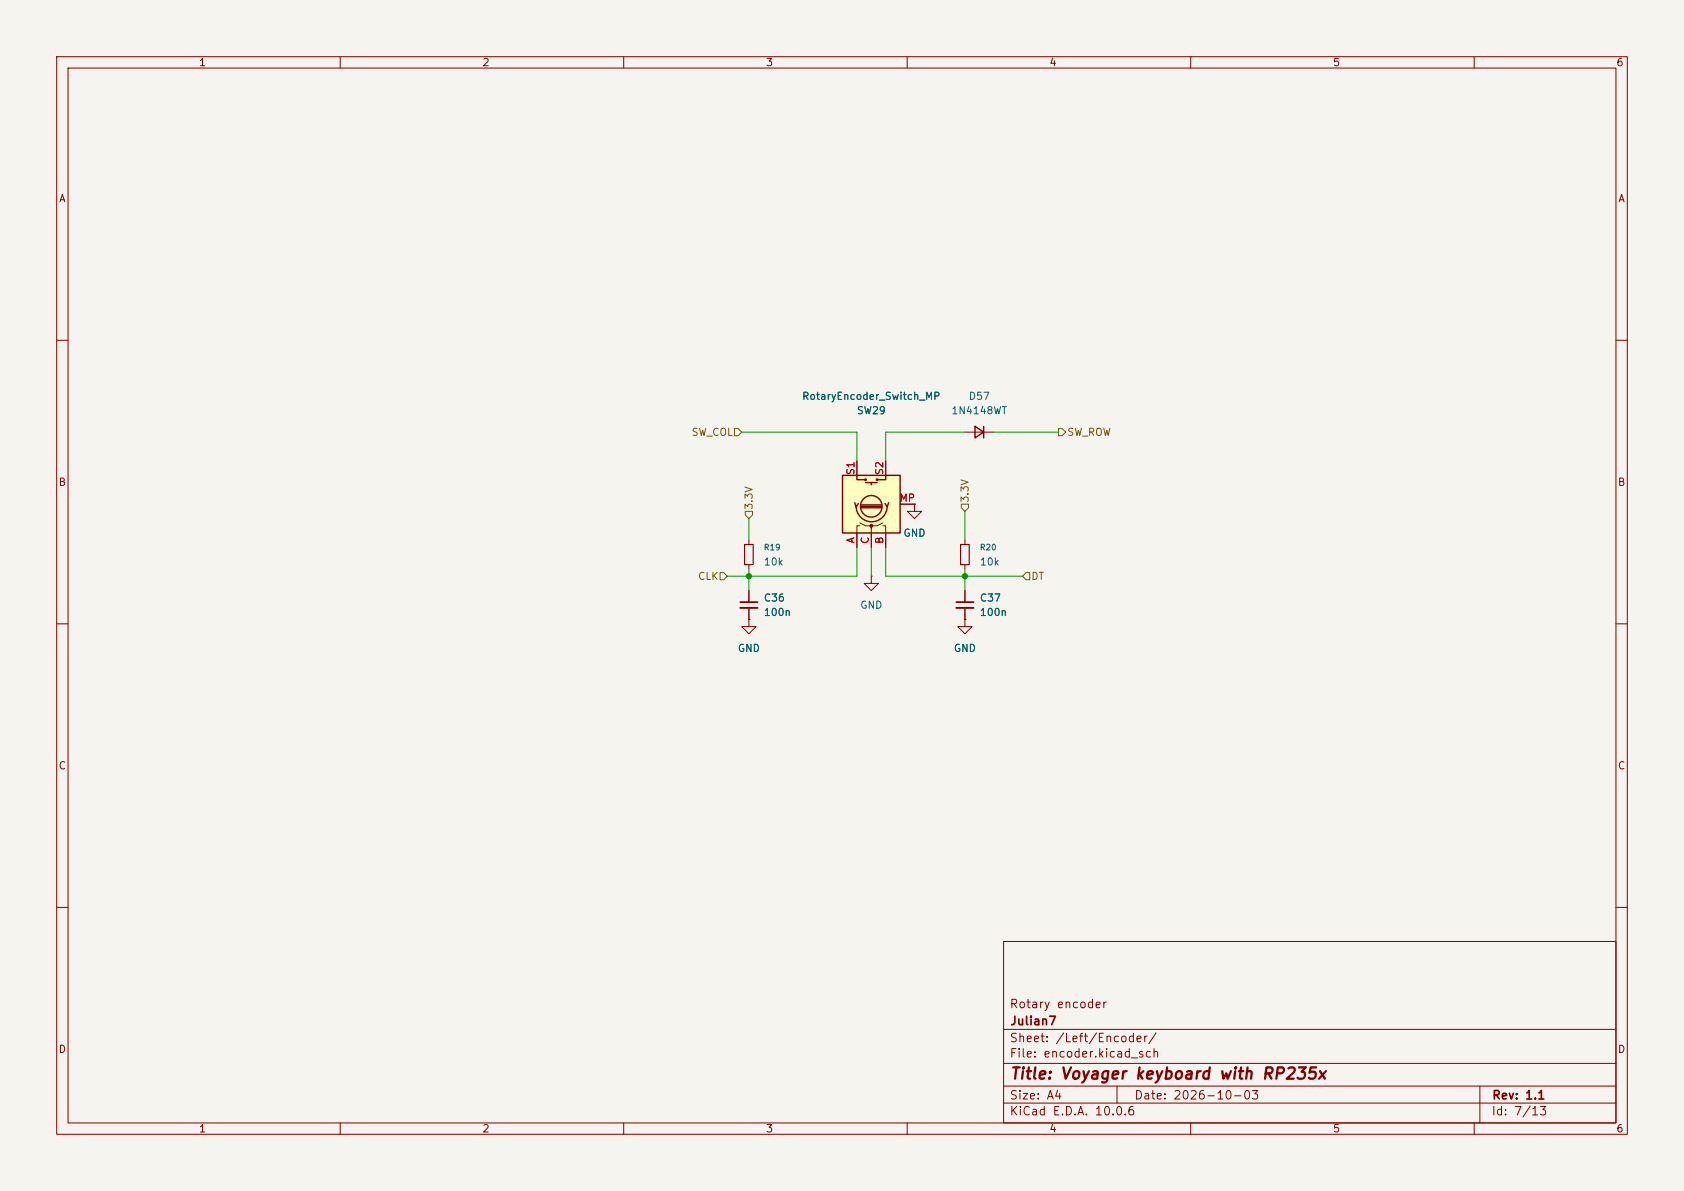
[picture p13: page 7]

Rotary encoder
Julian7
Sheet: /Left/Encoder/
File: encoder.kicad_sch
Title: Voyager keyboard with RP235x

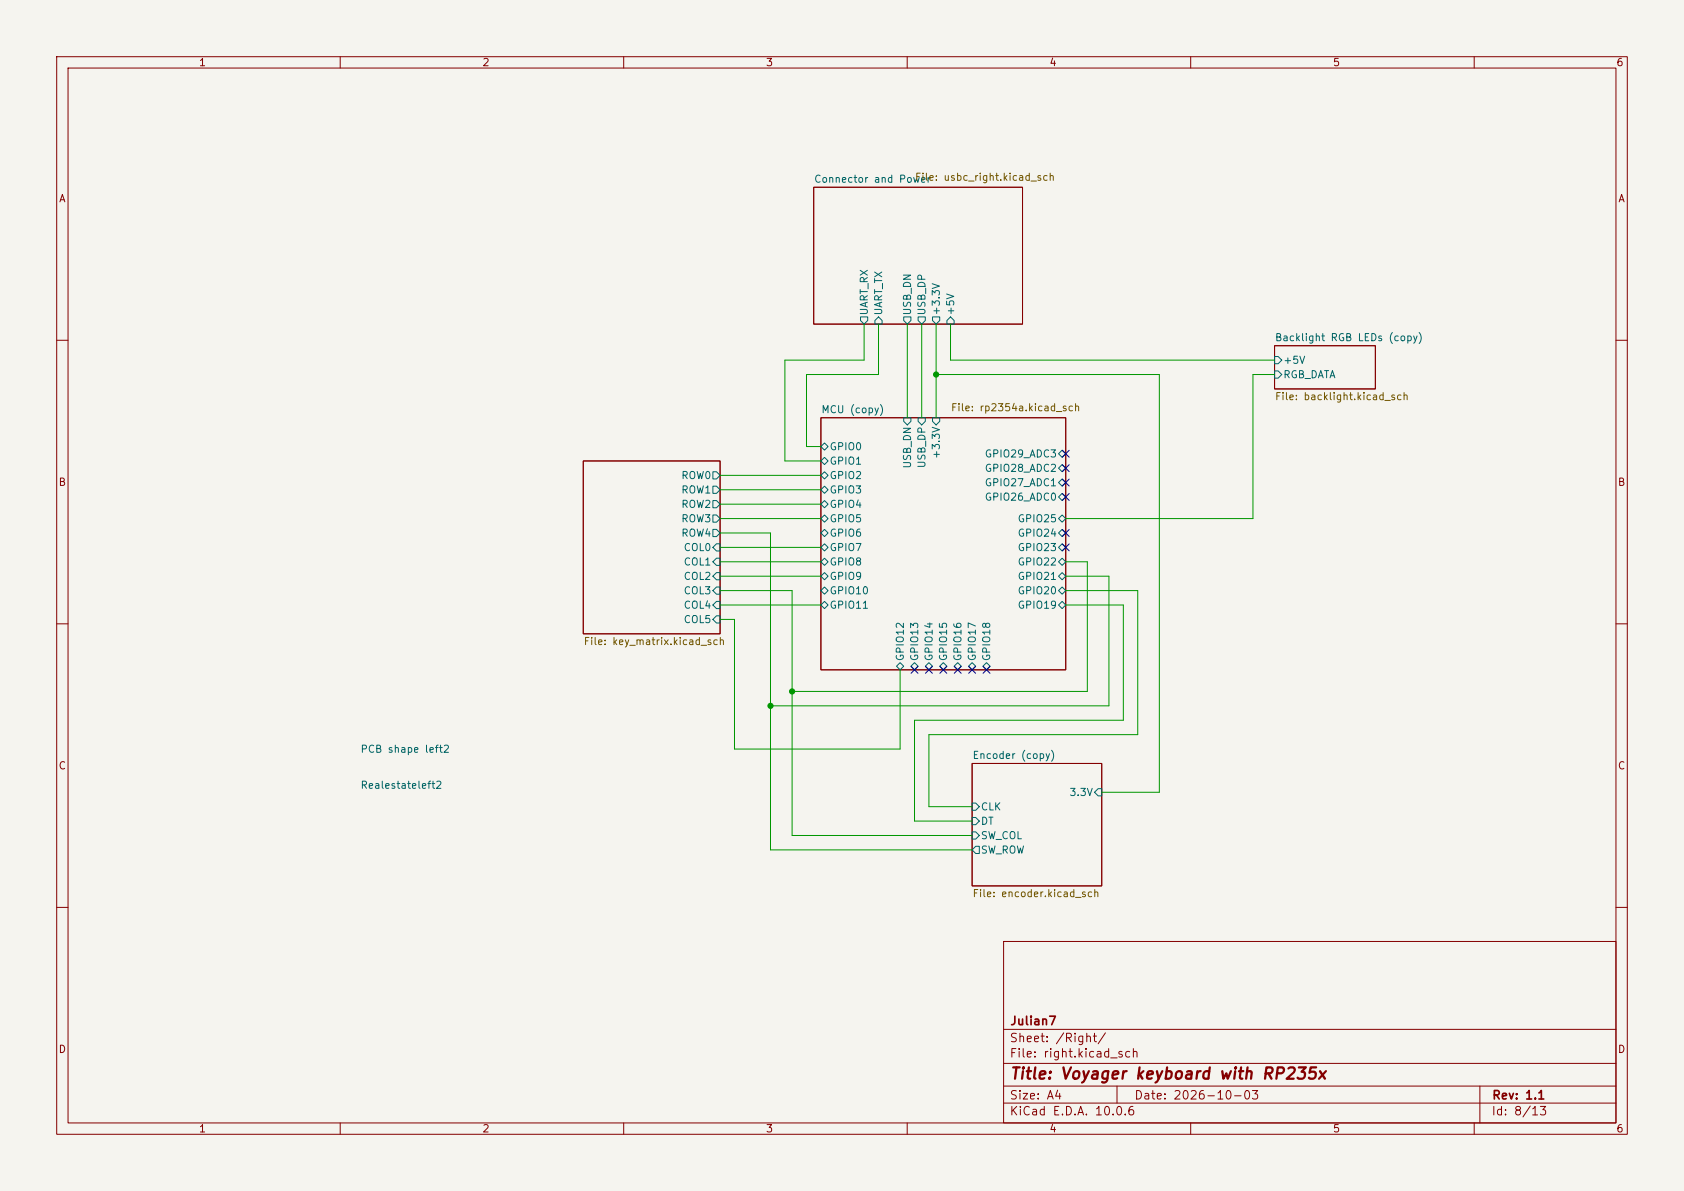
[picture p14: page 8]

Julian7
Sheet: /Right/
File: right.kicad_sch
Title: Voyager keyboard with RP235x

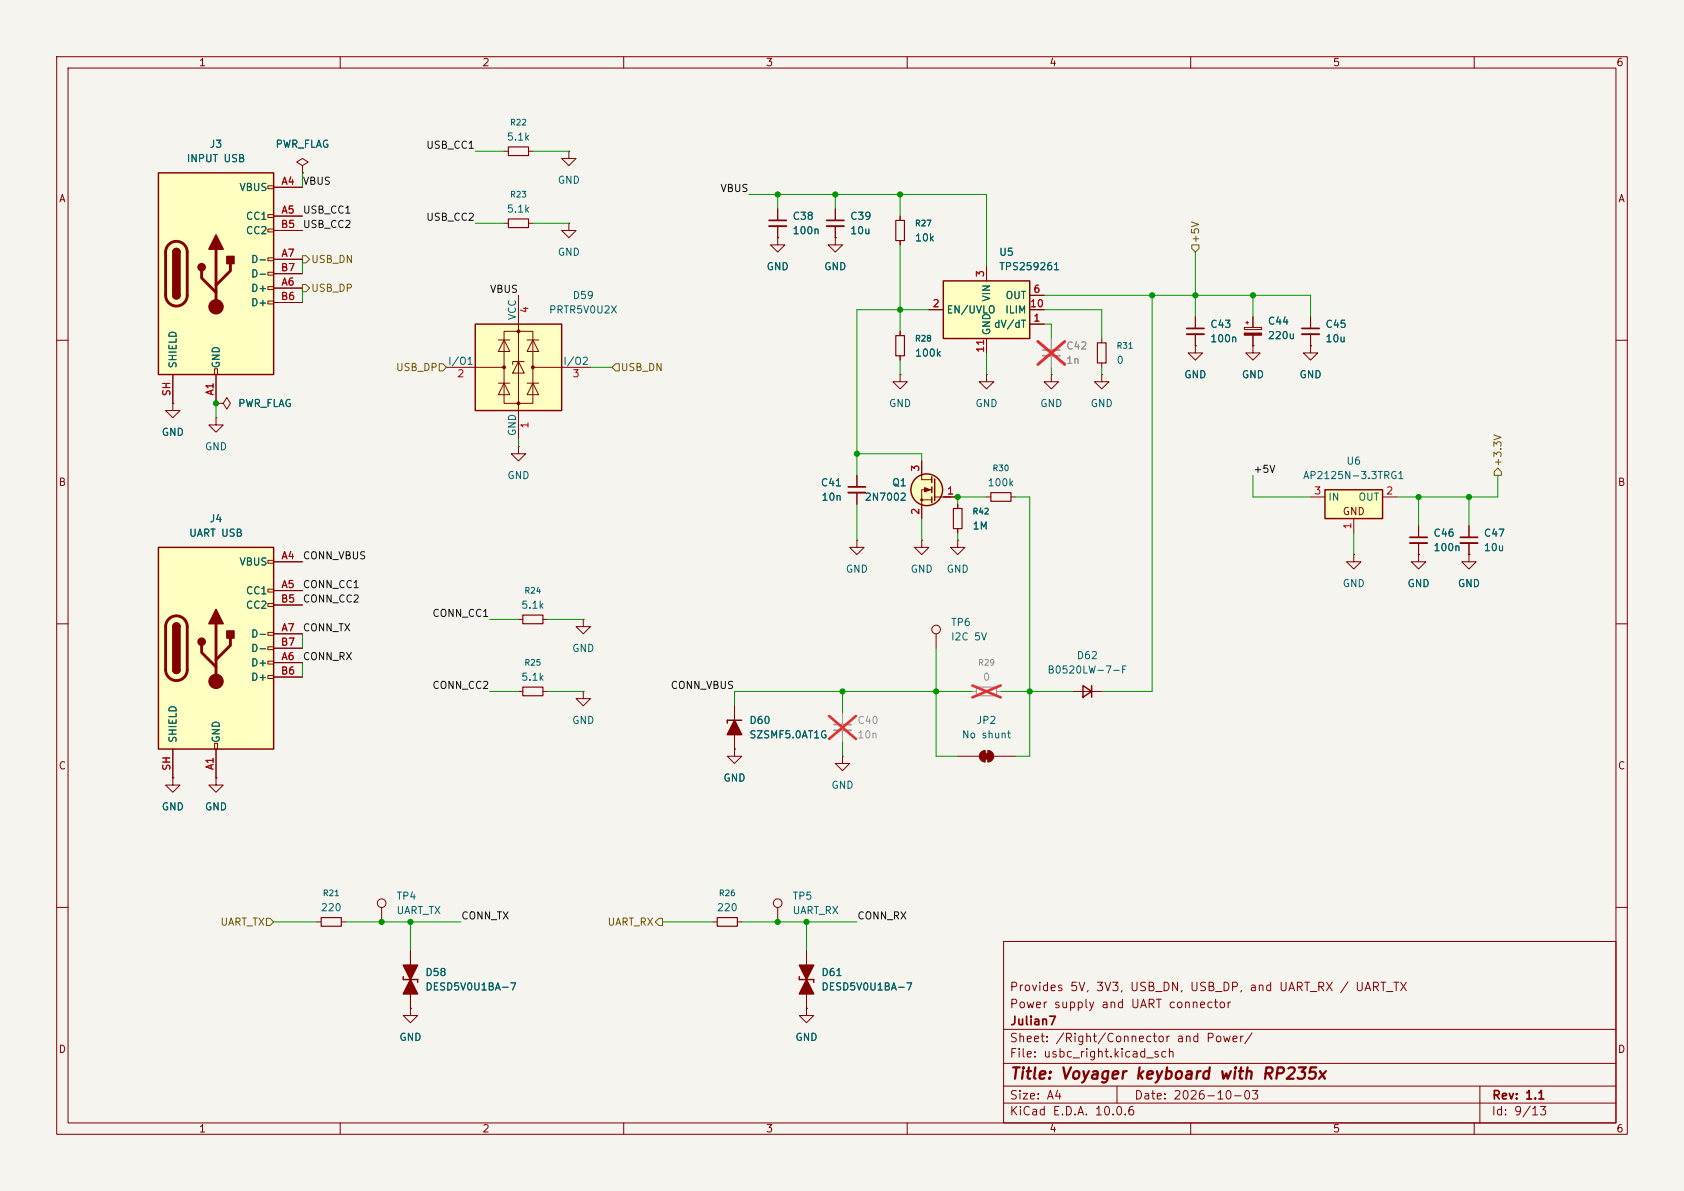
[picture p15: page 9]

Provides 5V, 3V3, USB_DN, USB_DP, and UART_RX / UART_TX
Power supply and UART connector
Julian7
Sheet: /Right/Connector and Power/
File: usbc_right.kicad_sch
Title: Voyager keyboard with RP235x

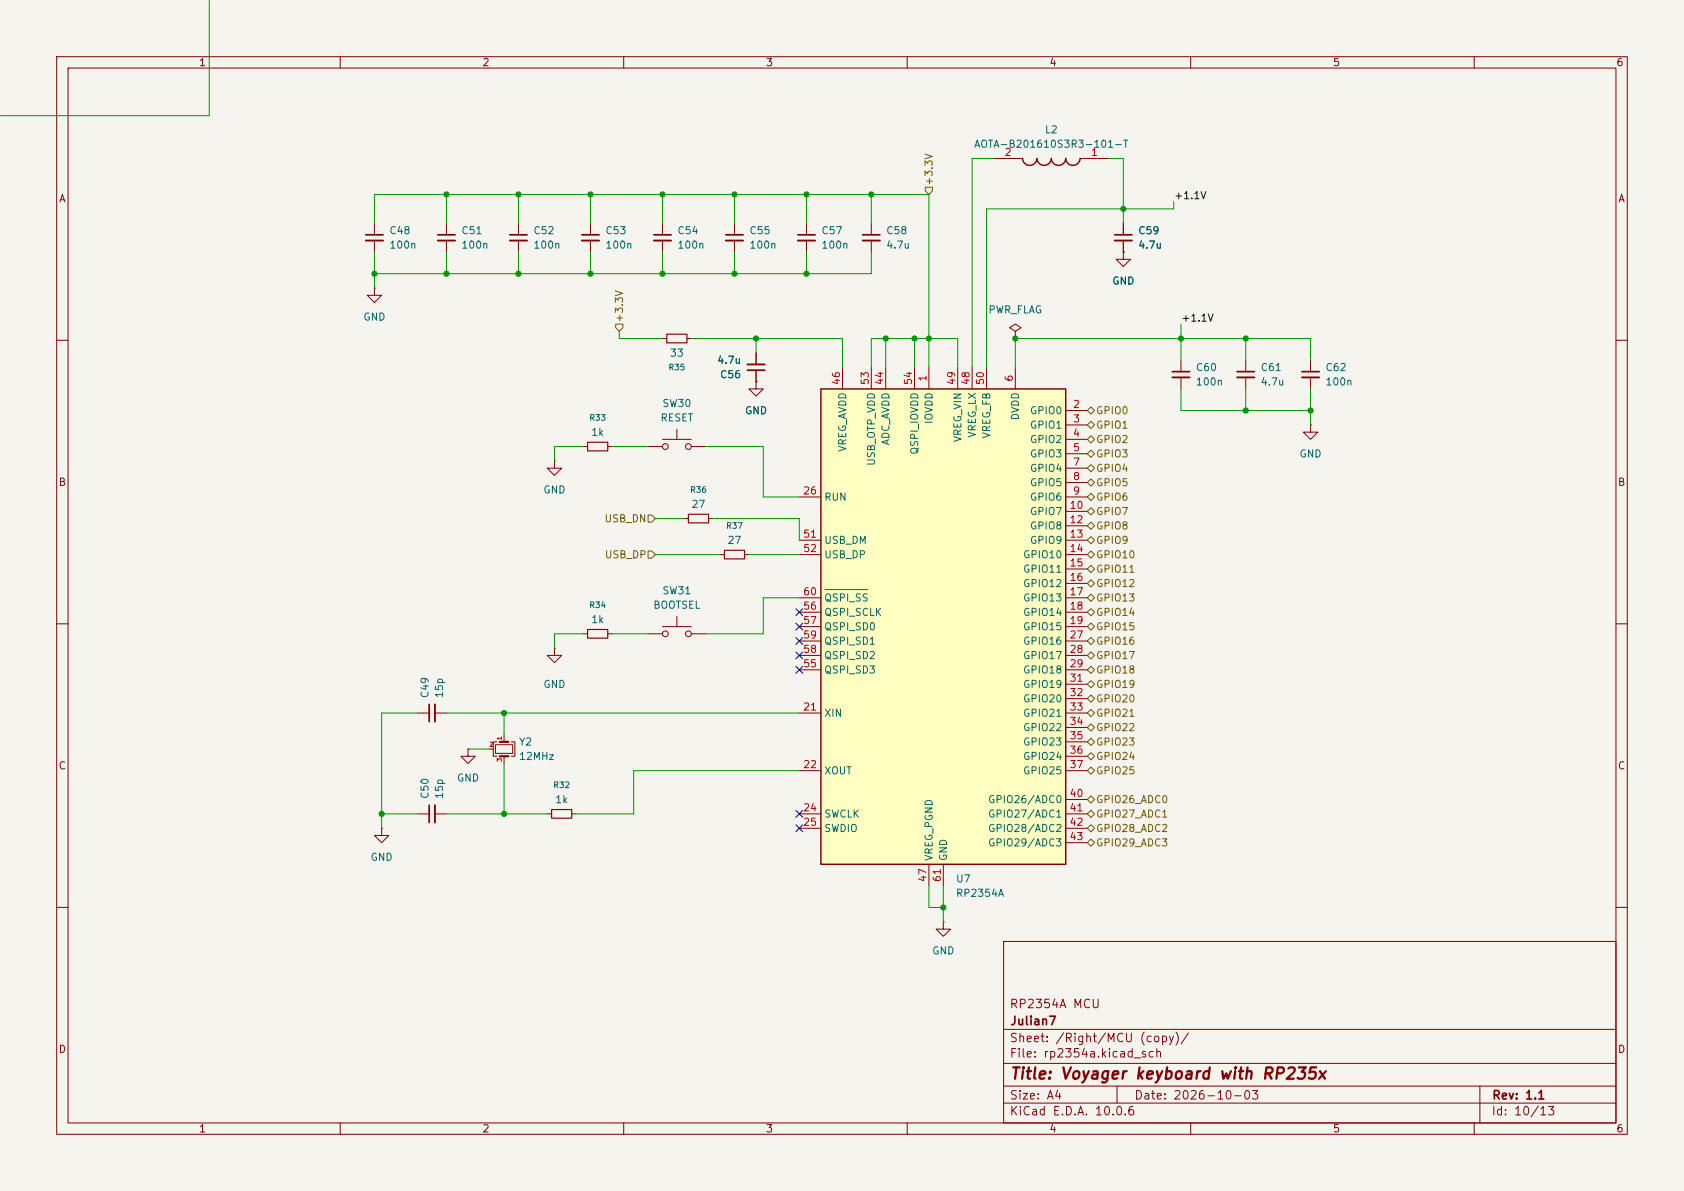
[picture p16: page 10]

RP2354A MCU
Julian7
Sheet: /Right/MCU (copy)/
File: rp2354a.kicad_sch
Title: Voyager keyboard with RP235x

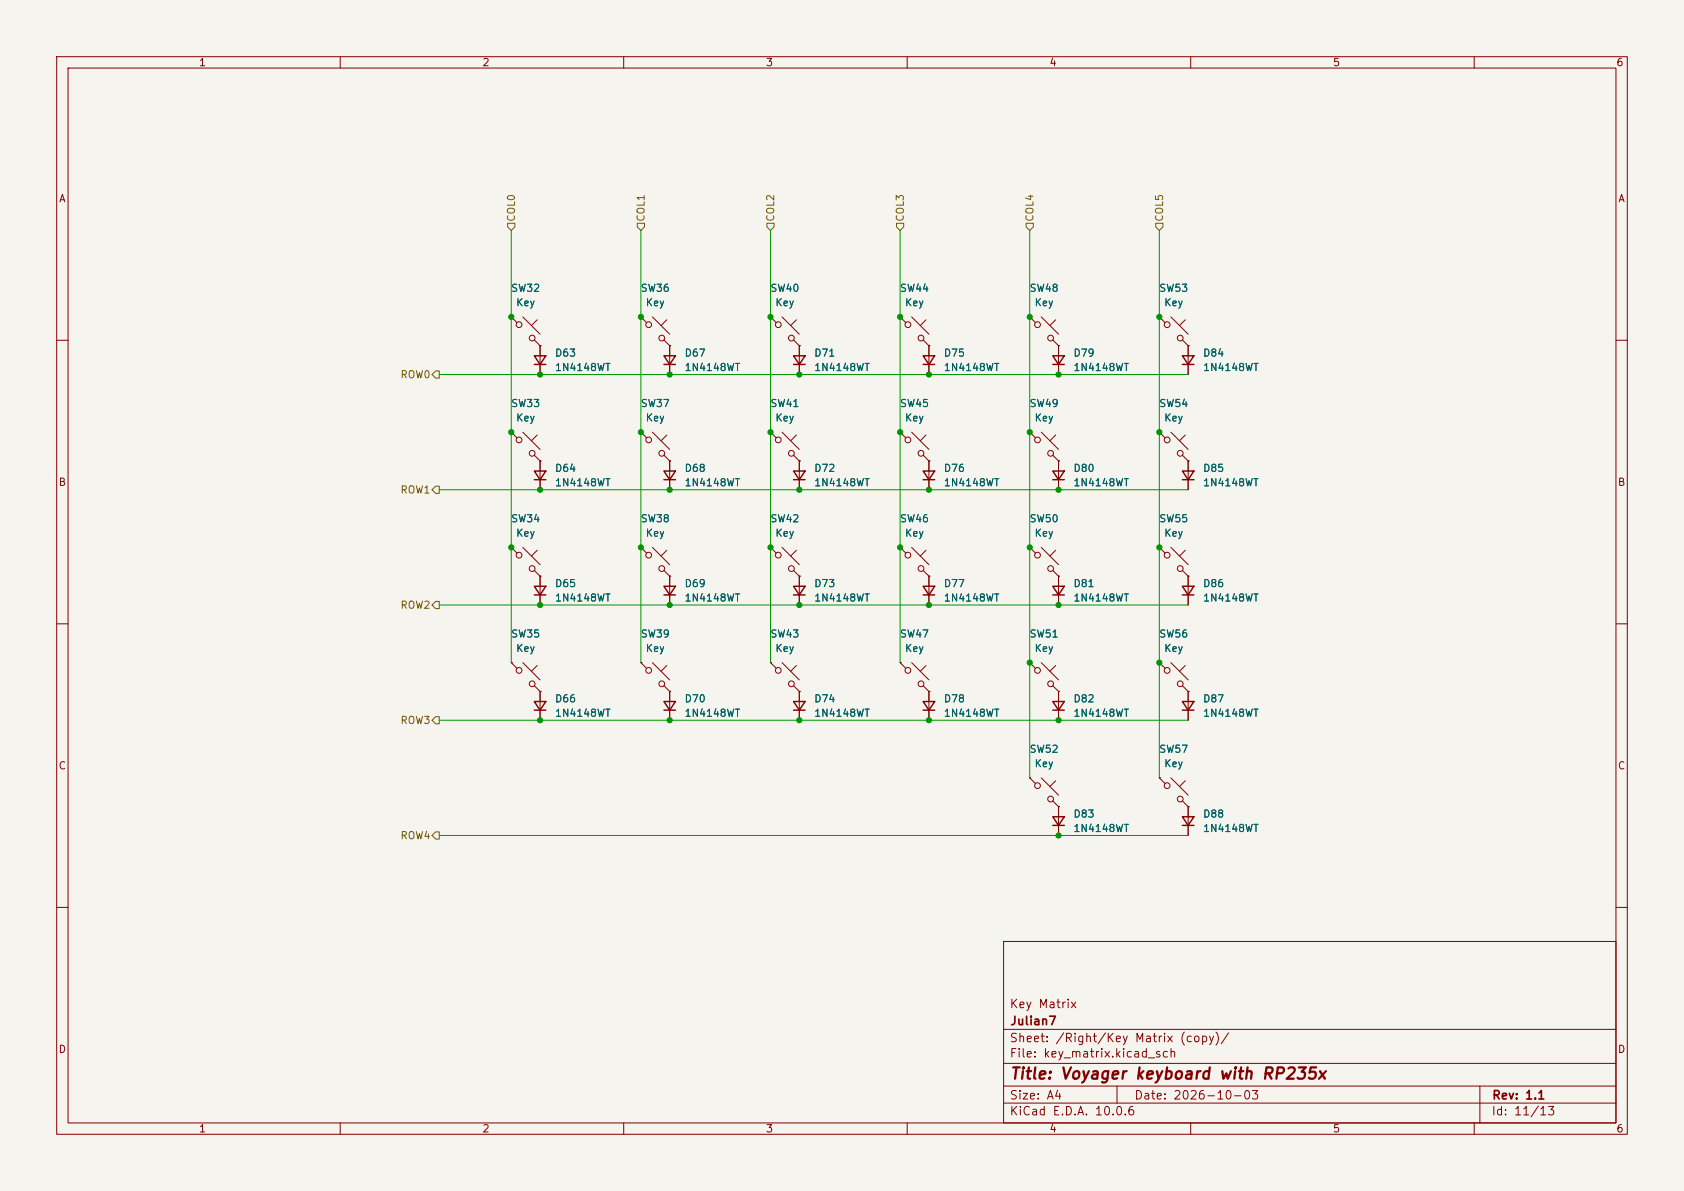
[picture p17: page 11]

Key Matrix
Julian7
Sheet: /Right/Key Matrix (copy)/
File: key_matrix.kicad_sch
Title: Voyager keyboard with RP235x

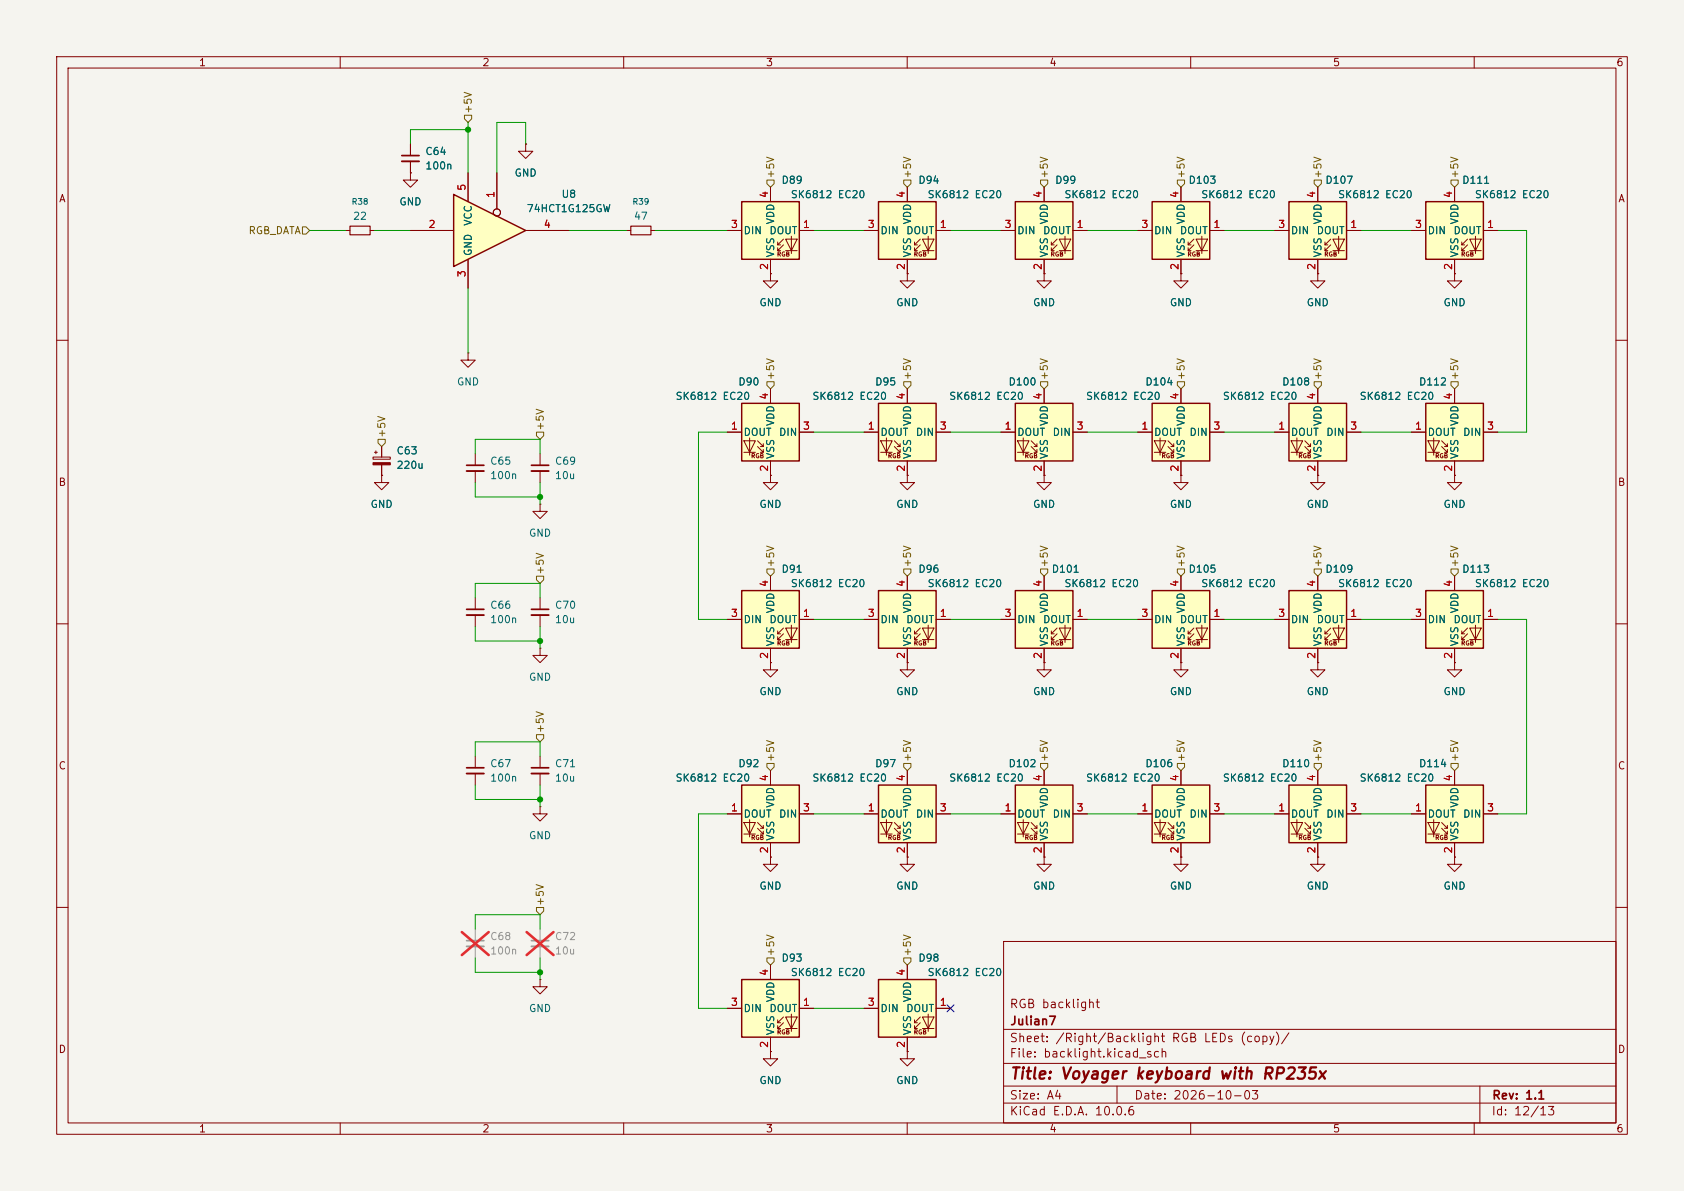
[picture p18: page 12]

Julian7
Sheet: /Right/Backlight RGB LEDs (copy)/
File: backlight.kicad_sch
Title: Voyager keyboard with RP235x


Rotary encoder
Julian7
Sheet: /Right/Encoder (copy)/
File: encoder.kicad_sch
Title: Voyager keyboard with RP235x

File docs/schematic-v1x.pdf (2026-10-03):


Size: A4 | Rev: 1.1
KiCad E.D.A. 10.0.6 | Id: 1/13


Julian7
Sheet: /Left/
File: left.kicad_sch
Title: Voyager keyboard with RP235x

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



Key Matrix
Julian7
Sheet: /Left/Key Matrix/
File: key_matrix.kicad_sch
Title: Voyager keyboard with RP235x


Julian7
Sheet: /Left/Backlight RGB LEDs/
File: backlight.kicad_sch
Title: Voyager keyboard with RP235x


Rotary encoder
Julian7
Sheet: /Left/Encoder/
File: encoder.kicad_sch
Title: Voyager keyboard with RP235x


Julian7
Sheet: /Right/
File: right.kicad_sch
Title: Voyager keyboard with RP235x

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


RP2354A MCU
Julian7
Sheet: /Right/MCU (copy)/
File: rp2354a.kicad_sch
Title: Voyager keyboard with RP235x


Key Matrix
Julian7
Sheet: /Right/Key Matrix (copy)/
File: key_matrix.kicad_sch
Title: Voyager keyboard with RP235x


Julian7
Sheet: /Right/Backlight RGB LEDs (copy)/
File: backlight.kicad_sch
Title: Voyager keyboard with RP235x


Rotary encoder
Julian7
Sheet: /Right/Encoder (copy)/
File: encoder.kicad_sch
Title: Voyager keyboard with RP235x





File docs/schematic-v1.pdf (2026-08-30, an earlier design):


Size: A4 | Rev: 0
KiCad E.D.A. 10.0.5 | Id: 1/13


Julian7
Sheet: /Left/
File: left.kicad_sch
Title: Voyager keyboard with RP235x


Provides 5V, 3V3, USB_DN, USB_DP, and UART_RX / UART_TX
Power supply and UART connector
Julian7
Sheet: /Left/Connector and Power/
File: usbc.kicad_sch
Title: Voyager keyboard with RP235x



Key Matrix
Julian7
Sheet: /Left/Key Matrix/
File: key_matrix.kicad_sch
Title: Voyager keyboard with RP235x


Julian7
Sheet: /Left/Backlight RGB LEDs/
File: backlight.kicad_sch
Title: Voyager keyboard with RP235x


Rotary encoder
Julian7
Sheet: /Left/Encoder/
File: encoder.kicad_sch
Title: Voyager keyboard with RP235x


Julian7
Sheet: /Right/
File: right.kicad_sch
Title: Voyager keyboard with RP235x


Provides 5V, 3V3, USB_DN, USB_DP, and UART_RX / UART_TX
Power supply and UART connector
Julian7
Sheet: /Right/Connector and Power/
File: usbc_right.kicad_sch
Title: Voyager keyboard with RP235x


RP2354A MCU
Julian7
Sheet: /Right/MCU (copy)/
File: rp2354a.kicad_sch
Title: Voyager keyboard with RP235x


Key Matrix
Julian7
Sheet: /Right/Key Matrix (copy)/
File: key_matrix.kicad_sch
Title: Voyager keyboard with RP235x


Julian7
Sheet: /Right/Backlight RGB LEDs (copy)/
File: backlight.kicad_sch
Title: Voyager keyboard with RP235x


Rotary encoder
Julian7
Sheet: /Right/Encoder (copy)/
File: encoder.kicad_sch
Title: Voyager keyboard with RP235x

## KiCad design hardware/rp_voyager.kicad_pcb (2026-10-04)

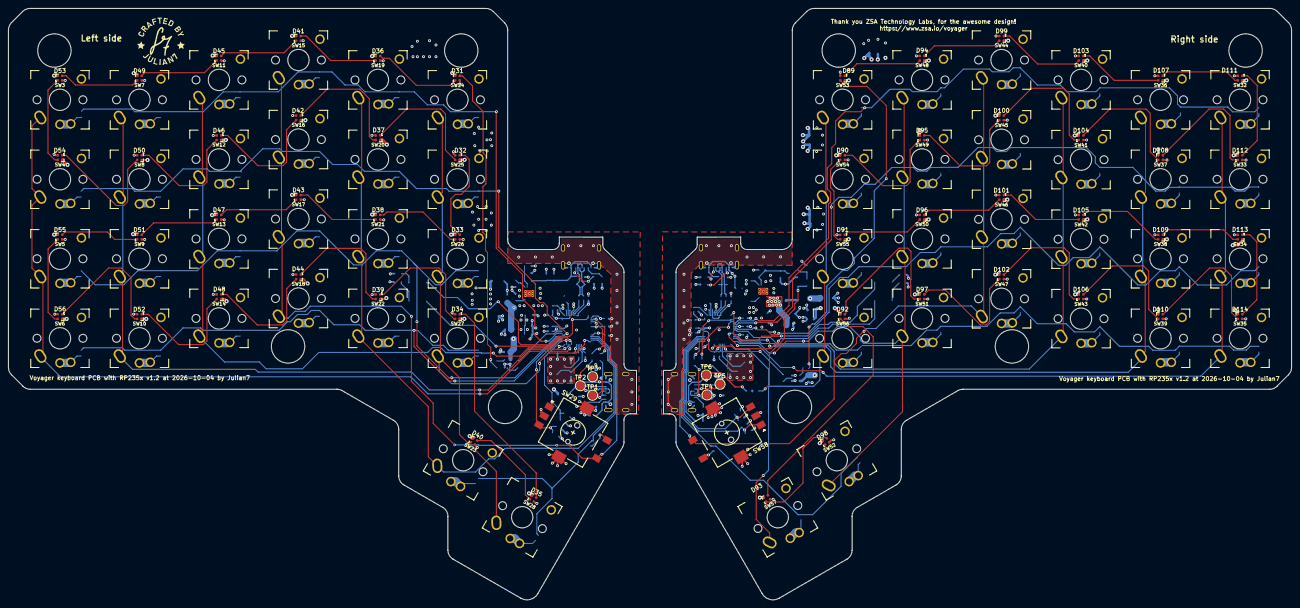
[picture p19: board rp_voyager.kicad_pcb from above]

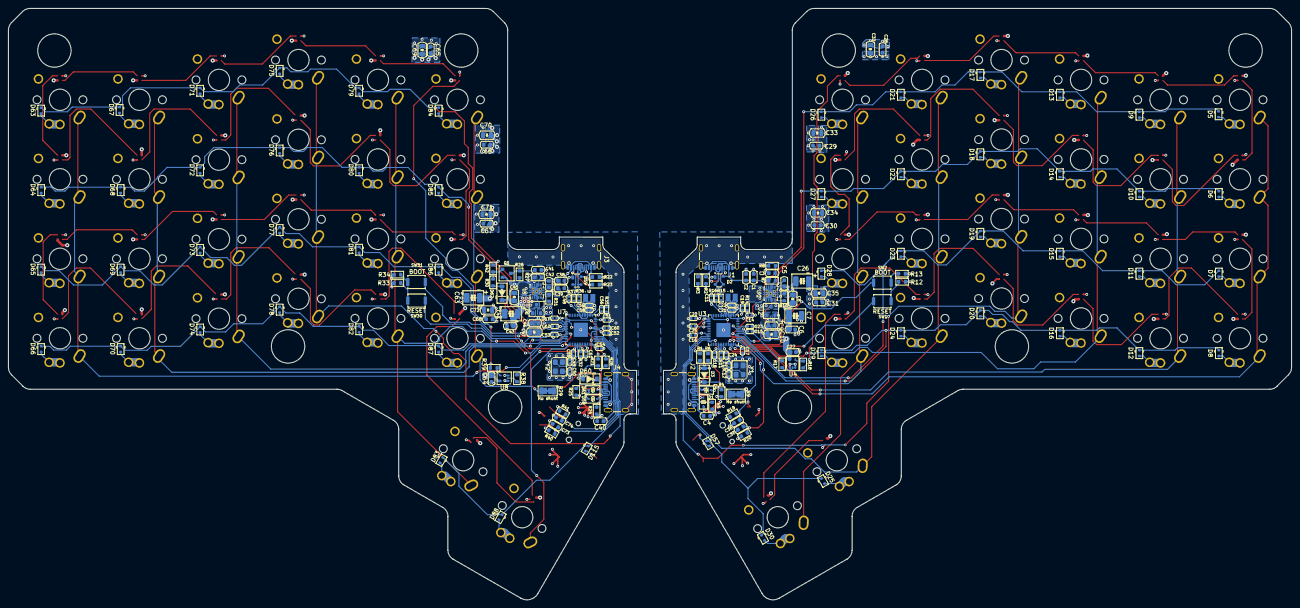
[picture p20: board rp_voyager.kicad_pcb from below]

Board: 4 copper layers, 307.5 x 141.7 mm, 317 parts (202 on the bottom side), 199 nets.

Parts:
C1, C6, C9, C27, C28, C29, C30, C31, C36, C37, C38, C43, C46, C64, C65, C66, C67, C68, C73, C74: 100n; C_0603_1608Metric
C2, C39: 10u; C_0603_1608Metric
C3, C4, C40, C41: 10n; C_0603_1608Metric
C5, C42: 1n; C_0603_1608Metric
C7, C26, C44, C63: 220u; CP_EIA-3528-21_Kemet-B
C8, C10, C32, C33, C34, C35, C45, C47, C69, C70, C71, C72: 10u; C_0805_2012Metric
C11, C14, C15, C16, C17, C18, C20, C23, C25, C48, C51, C52, C53, C54, C55, C57, C60, C62: 100n; C_0402_1005Metric
C12, C13, C49, C50: 15p; C_0402_1005Metric
C19, C21, C22, C24, C56, C58, C59, C61: 4.7u; C_0402_1005Metric
D1, D4, D58, D61: DESD5V0U1BA-7; D_SOD-323_TVS
D2, D59: PRTR5V0U2X; SOT-143
D3, D60: SZSMF5.0AT1G; D_SOD-123_Zener
D5, D6, D7, D8, D9, D10, D11, D12, D13, D14, D15, D16, D17, D18, D19, D20, D21, D22, D23, D24, D25, D26, D27, D28, D29, D30, D57, D63, D64, D65, D66, D67, D68, D69, D70, D71, D72, D73, D74, D75, D76, D77, D78, D79, D80, D81, D82, D83, D84, D85, D86, D87, D88, D115: 1N4148WT; D_SOD-523
D31, D32, D33, D34, D35, D36, D37, D38, D39, D40, D41, D42, D43, D44, D45, D46, D47, D48, D49, D50, D51, D52, D53, D54, D55, D56, D89, D90, D91, D92, D93, D94, D95, D96, D97, D98, D99, D100, D101, D102, D103, D104, D105, D106, D107, D108, D109, D110, D111, D112, D113, D114: SK6812 EC20; LED_SK6812_EC20_2x2mm
D62: B0520LW-7-F; D_SOD-123
J1, J3: INPUT USB; USB_C_Receptacle_GCT_USB4105-xx-A_16P_TopMnt_Horizontal
J2, J4: UART USB; USB_C_Receptacle_GCT_USB4105-xx-A_16P_TopMnt_Horizontal
L1, L2: AOTA-B201610S3R3-101-T; INDC2016X100N
PCB shape left1, PCB shape left2: PCB left
Q1: 2N7002; SOT-23
R1, R6, R21, R26: 220; R_0603_1608Metric
R2, R3, R4, R5, R22, R23, R24, R25: 5.1k; R_0603_1608Metric
R7, R19, R20, R27, R40, R41: 10k; R_0603_1608Metric
R8, R28, R30: 100k; R_0603_1608Metric
R9, R29: 0; R_1206_3216Metric_WireJumper
R10, R31: 0; R_0603_1608Metric
R11, R32: 1k; R_0402_1005Metric
R12, R13, R33, R34: 1k; R_0603_1608Metric
R14, R35: 33; R_0402_1005Metric
R15, R16, R36, R37: 27; R_0402_1005Metric
R17, R38: 22; R_0603_1608Metric
R18, R39: 47; R_0603_1608Metric
R42: 1M; R_0603_1608Metric
Realestateleft1, Realestateleft2: Realestate left
SW1, SW30: RESET; SW_Push_SPST_NO_Alps_SKRK
SW2, SW31: BOOTSEL; SW_Push_SPST_NO_Alps_SKRK
SW3, SW4, SW5, SW6, SW7, SW8, SW9, SW10, SW11, SW12, SW13, SW14, SW15, SW16, SW17, SW18, SW19, SW20, SW21, SW22, SW23, SW24, SW25, SW26, SW27, SW32, SW33, SW34, SW35, SW36, SW37, SW38, SW39, SW40, SW41, SW42, SW43, SW44, SW45, SW46, SW47, SW48, SW49, SW50, SW51, SW52, SW53, SW54, SW55, SW56: Key; Gateron-KS33-Solderable-1U
SW28, SW57: Key; Gateron-KS33-Solderable-1x1.5U
SW29, SW58: RotaryEncoder_Switch_MP; RotaryEncoder_Alps_EC11S-Switch_Vertical_H9mm
TP1, TP4: UART_TX; TestPoint_Pad_D2.0mm
TP2, TP5: UART_RX; TestPoint_Pad_D2.0mm
TP3, TP6: I2C 5V; TestPoint_Pad_D2.0mm
U1, U5: TPS259261; VSON-10-1EP_3x3mm_P0.5mm_EP1.65x2.4mm_ThermalVias
U2, U6: AP2125N-3.3TRG1; SOT-23
U3, U7: RP2354A; QFN-60-1EP_7x7mm_P0.4mm_EP3.4x3.4mm
U4, U8: 74HCT1G125GW; SOT-353_SC-70-5
Y1, Y2: 12MHz; Crystal_SMD_Abracon_ABM8G-4Pin_3.2x2.5mm
makersmark1: julian7_makers_mark

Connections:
/Left/Backlight RGB LEDs/RGB_DATA: R17.1, U3.37 (GPIO25)
/Left/Connector and Power/+3.3V: C9.1, C10.1, C11.1, C14.1, C15.1, C16.1, C17.1, C18.1, C20.1, C21.1, R14.1, R19.2, R20.2, U2.2 (OUT), U3.1 (IOVDD), U3.11 (IOVDD), U3.20 (IOVDD), U3.30 (IOVDD), U3.38 (IOVDD), U3.44 (ADC_AVDD), U3.45 (IOVDD), U3.49 (VREG_VIN), U3.53 (USB_OTP_VDD), U3.54 (QSPI_IOVDD)
/Left/Connector and Power/+5V: C6.1, C7.1, C8.1, C26.1, C27.1, C28.1, C29.1, C30.1, C31.1, C32.1, C33.1, C34.1, C35.1, D31.4 (VDD), D32.4 (VDD), D33.4 (VDD), D34.4 (VDD), D35.4 (VDD), D36.4 (VDD), D37.4 (VDD), D38.4 (VDD), D39.4 (VDD), D40.4 (VDD), D41.4 (VDD), D42.4 (VDD), D43.4 (VDD), D44.4 (VDD), D45.4 (VDD), D46.4 (VDD), D47.4 (VDD), D48.4 (VDD), D49.4 (VDD), D50.4 (VDD), D51.4 (VDD), D52.4 (VDD), D53.4 (VDD), D54.4 (VDD), D55.4 (VDD), D56.4 (VDD), R9.1, U1.6 (OUT), U1.7 (OUT), U1.8 (OUT), U2.3 (IN), U4.5 (VCC)
/Left/Connector and Power/CONN_CC1: J2.A5 (CC1), R4.1
/Left/Connector and Power/CONN_CC2: J2.B5 (CC2), R5.1
/Left/Connector and Power/CONN_RX: D4.2 (A), J2.A7 (D-), J2.B7 (D-), R6.1, TP2.1 (1_1)
/Left/Connector and Power/CONN_TX: D1.2 (A), J2.A6 (D+), J2.B6 (D+), R1.1, TP1.1 (1_1)
/Left/Connector and Power/CONN_VBUS: C4.1, D3.1 (K), J2.A4 (VBUS), J2.A9 (VBUS), J2.B4 (VBUS), J2.B9 (VBUS), R9.2, TP3.1 (1_1)
/Left/Connector and Power/UART_RX: R6.2, U3.3 (GPIO1)
/Left/Connector and Power/UART_TX: R1.2, U3.2 (GPIO0)
/Left/Connector and Power/USB_CC1: J1.A5 (CC1), R2.1
/Left/Connector and Power/USB_CC2: J1.B5 (CC2), R3.1
/Left/Connector and Power/USB_DN: D2.3 (I/O2), J1.A7 (D-), J1.B7 (D-), R15.1
/Left/Connector and Power/USB_DP: D2.2 (I/O1), J1.A6 (D+), J1.B6 (D+), R16.1
/Left/Connector and Power/VBUS: C1.1, C2.1, D2.4 (VCC), J1.A4 (VBUS), J1.A9 (VBUS), J1.B4 (VBUS), J1.B9 (VBUS), R7.2, U1.3 (VIN), U1.4 (VIN), U1.5 (VIN)
/Left/Encoder/CLK: C36.1, R19.1, SW29.A, U3.31 (GPIO19)
/Left/Encoder/DT: C37.1, R20.1, SW29.B, U3.32 (GPIO20)
/Left/Encoder/SW_COL: SW15.1, SW16.1, SW17.1, SW18.1, SW29.S1, U3.12 (GPIO8)
/Left/Encoder/SW_ROW: D25.1 (K), D30.1 (K), D57.1 (K), U3.13 (GPIO9)
/Left/Key Matrix/COL0: SW3.1, SW4.1, SW5.1, SW6.1, U3.27 (GPIO16)
/Left/Key Matrix/COL1: SW7.1, SW8.1, SW9.1, SW10.1, U3.28 (GPIO17)
/Left/Key Matrix/COL2: SW11.1, SW12.1, SW13.1, SW14.1, U3.29 (GPIO18)
/Left/Key Matrix/COL4: SW19.1, SW20.1, SW21.1, SW22.1, SW23.1, U3.14 (GPIO10)
/Left/Key Matrix/COL5: SW24.1, SW25.1, SW26.1, SW27.1, SW28.1, U3.15 (GPIO11)
/Left/Key Matrix/ROW0: D5.1 (K), D9.1 (K), D13.1 (K), D17.1 (K), D21.1 (K), D26.1 (K), U3.36 (GPIO24)
/Left/Key Matrix/ROW1: D6.1 (K), D10.1 (K), D14.1 (K), D18.1 (K), D22.1 (K), D27.1 (K), U3.35 (GPIO23)
/Left/Key Matrix/ROW2: D7.1 (K), D11.1 (K), D15.1 (K), D19.1 (K), D23.1 (K), D28.1 (K), U3.34 (GPIO22)
/Left/Key Matrix/ROW3: D8.1 (K), D12.1 (K), D16.1 (K), D20.1 (K), D24.1 (K), D29.1 (K), U3.33 (GPIO21)
/Left/MCU/+1.1V: C22.1, C23.1, C24.1, C25.1, L1.1, U3.6 (DVDD), U3.23 (DVDD), U3.39 (DVDD), U3.50 (VREG_FB)
/Right/Backlight RGB LEDs (copy)/RGB_DATA: R38.1, U7.37 (GPIO25)
/Right/Connector and Power/+3.3V: C46.1, C47.1, C48.1, C51.1, C52.1, C53.1, C54.1, C55.1, C57.1, C58.1, R35.1, R40.2, R41.2, U6.2 (OUT), U7.1 (IOVDD), U7.11 (IOVDD), U7.20 (IOVDD), U7.30 (IOVDD), U7.38 (IOVDD), U7.44 (ADC_AVDD), U7.45 (IOVDD), U7.49 (VREG_VIN), U7.53 (USB_OTP_VDD), U7.54 (QSPI_IOVDD)
/Right/Connector and Power/+5V: C43.1, C44.1, C45.1, C63.1, C64.1, C65.1, C66.1, C67.1, C68.1, C69.1, C70.1, C71.1, C72.1, D62.1 (K), D89.4 (VDD), D90.4 (VDD), D91.4 (VDD), D92.4 (VDD), D93.4 (VDD), D94.4 (VDD), D95.4 (VDD), D96.4 (VDD), D97.4 (VDD), D98.4 (VDD), D99.4 (VDD), D100.4 (VDD), D101.4 (VDD), D102.4 (VDD), D103.4 (VDD), D104.4 (VDD), D105.4 (VDD), D106.4 (VDD), D107.4 (VDD), D108.4 (VDD), D109.4 (VDD), D110.4 (VDD), D111.4 (VDD), D112.4 (VDD), D113.4 (VDD), D114.4 (VDD), U5.6 (OUT), U5.7 (OUT), U5.8 (OUT), U6.3 (IN), U8.5 (VCC)
/Right/Connector and Power/CONN_CC1: J4.A5 (CC1), R24.1
/Right/Connector and Power/CONN_CC2: J4.B5 (CC2), R25.1
/Right/Connector and Power/CONN_RX: D61.2 (A), J4.A6 (D+), J4.B6 (D+), R26.1, TP5.1 (1_1)
/Right/Connector and Power/CONN_TX: D58.2 (A), J4.A7 (D-), J4.B7 (D-), R21.1, TP4.1 (1_1)
/Right/Connector and Power/CONN_VBUS: C40.1, D60.1 (K), J4.A4 (VBUS), J4.A9 (VBUS), J4.B4 (VBUS), J4.B9 (VBUS), R29.2, TP6.1 (1_1)
/Right/Connector and Power/UART_RX: R26.2, U7.3 (GPIO1)
/Right/Connector and Power/UART_TX: R21.2, U7.2 (GPIO0)
/Right/Connector and Power/USB_CC1: J3.A5 (CC1), R22.1
/Right/Connector and Power/USB_CC2: J3.B5 (CC2), R23.1
/Right/Connector and Power/USB_DN: D59.3 (I/O2), J3.A7 (D-), J3.B7 (D-), R36.1
/Right/Connector and Power/USB_DP: D59.2 (I/O1), J3.A6 (D+), J3.B6 (D+), R37.1
/Right/Connector and Power/VBUS: C38.1, C39.1, D59.4 (VCC), J3.A4 (VBUS), J3.A9 (VBUS), J3.B4 (VBUS), J3.B9 (VBUS), R27.2, U5.3 (VIN), U5.4 (VIN), U5.5 (VIN)
/Right/Encoder (copy)/CLK: C73.1, R40.1, SW58.A, U7.32 (GPIO20)
/Right/Encoder (copy)/DT: C74.1, R41.1, SW58.B, U7.31 (GPIO19)
/Right/Encoder (copy)/SW_COL: SW44.1, SW45.1, SW46.1, SW47.1, SW58.S1, U7.34 (GPIO22)
/Right/Encoder (copy)/SW_ROW: D83.1 (K), D88.1 (K), D115.1 (K), U7.33 (GPIO21)
/Right/Key Matrix (copy)/COL0: SW32.1, SW33.1, SW34.1, SW35.1, U7.10 (GPIO7)
/Right/Key Matrix (copy)/COL1: SW36.1, SW37.1, SW38.1, SW39.1, U7.12 (GPIO8)
/Right/Key Matrix (copy)/COL2: SW40.1, SW41.1, SW42.1, SW43.1, U7.13 (GPIO9)
/Right/Key Matrix (copy)/COL4: SW48.1, SW49.1, SW50.1, SW51.1, SW52.1, U7.15 (GPIO11)
/Right/Key Matrix (copy)/COL5: SW53.1, SW54.1, SW55.1, SW56.1, SW57.1, U7.16 (GPIO12)
/Right/Key Matrix (copy)/ROW0: D63.1 (K), D67.1 (K), D71.1 (K), D75.1 (K), D79.1 (K), D84.1 (K), U7.4 (GPIO2)
/Right/Key Matrix (copy)/ROW1: D64.1 (K), D68.1 (K), D72.1 (K), D76.1 (K), D80.1 (K), D85.1 (K), U7.5 (GPIO3)
/Right/Key Matrix (copy)/ROW2: D65.1 (K), D69.1 (K), D73.1 (K), D77.1 (K), D81.1 (K), D86.1 (K), U7.7 (GPIO4)
/Right/Key Matrix (copy)/ROW3: D66.1 (K), D70.1 (K), D74.1 (K), D78.1 (K), D82.1 (K), D87.1 (K), U7.8 (GPIO5)
/Right/MCU (copy)/+1.1V: C59.1, C60.1, C61.1, C62.1, L2.1, U7.6 (DVDD), U7.23 (DVDD), U7.39 (DVDD), U7.50 (VREG_FB)
GND: C1.2, C2.2, C3.2, C4.2, C5.2, C6.2, C7.2, C8.2, C9.2, C10.2, C11.2, C12.1, C13.1, C14.2, C15.2, C16.2, C17.2, C18.2, C19.1, C20.2, C21.2, C22.2, C23.2, C24.2, C25.2, C26.2, C27.2, C28.2, C29.2, C30.2, C31.2, C32.2, C33.2, C34.2, C35.2, C36.2, C37.2, C38.2, C39.2, C40.2, C41.2, C42.2, C43.2, C44.2, C45.2, C46.2, C47.2, C48.2, C49.1, C50.1, C51.2, C52.2, C53.2, C54.2, C55.2, C56.1, C57.2, C58.2, C59.2, C60.2, C61.2, C62.2, C63.2, C64.2, C65.2, C66.2, C67.2, C68.2, C69.2, C70.2, C71.2, C72.2, C73.2, C74.2, D1.1 (K), D2.1 (GND), D3.2 (A), D4.1 (K), D31.2 (VSS), D32.2 (VSS), D33.2 (VSS), D34.2 (VSS), D35.2 (VSS), D36.2 (VSS), D37.2 (VSS), D38.2 (VSS), D39.2 (VSS), D40.2 (VSS), D41.2 (VSS), D42.2 (VSS), D43.2 (VSS), D44.2 (VSS), D45.2 (VSS), D46.2 (VSS), D47.2 (VSS), D48.2 (VSS), D49.2 (VSS), D50.2 (VSS), D51.2 (VSS), D52.2 (VSS), D53.2 (VSS), D54.2 (VSS), D55.2 (VSS), D56.2 (VSS), D58.1 (K), D59.1 (GND), D60.2 (A), D61.1 (K), D89.2 (VSS), D90.2 (VSS), D91.2 (VSS), D92.2 (VSS), D93.2 (VSS), D94.2 (VSS), D95.2 (VSS), D96.2 (VSS), D97.2 (VSS), D98.2 (VSS), D99.2 (VSS), D100.2 (VSS), D101.2 (VSS), D102.2 (VSS), D103.2 (VSS), D104.2 (VSS), D105.2 (VSS), D106.2 (VSS), D107.2 (VSS), D108.2 (VSS), D109.2 (VSS), D110.2 (VSS), D111.2 (VSS), D112.2 (VSS), D113.2 (VSS), D114.2 (VSS), J1.A1 (GND), J1.A12 (GND), J1.B1 (GND), J1.B12 (GND), J1.SH (SHIELD), J2.A1 (GND), J2.A12 (GND), J2.B1 (GND), J2.B12 (GND), J2.SH (SHIELD), J3.A1 (GND), J3.A12 (GND), J3.B1 (GND), J3.B12 (GND), J3.SH (SHIELD), J4.A1 (GND), J4.A12 (GND), J4.B1 (GND), J4.B12 (GND), J4.SH (SHIELD), Q1.2 (S), R2.2, R3.2, R4.2, R5.2, R8.1, R10.1, R12.1, R13.1, R22.2, R23.2, R24.2, R25.2, R28.1, R31.1, R33.1, R34.1, R42.2, SW29.C, SW29.MP, SW58.C, SW58.MP, U1.11 (GND), U2.1, U3.47 (VREG_PGND), U3.61 (GND), U4.1, U4.3 (GND), U5.11 (GND), U6.1, U7.47 (VREG_PGND), U7.61 (GND), U8.1, U8.3 (GND), Y1.2 (G), Y1.4 (G), Y2.2 (G), Y2.4 (G)
unnamed: C13.2, R11.1, Y1.3
unnamed: C50.2, R32.1, Y2.3
unnamed: D5.2 (A), SW3.2
unnamed: D6.2 (A), SW4.2
unnamed: D7.2 (A), SW5.2
unnamed: D8.2 (A), SW6.2
unnamed: D9.2 (A), SW7.2
unnamed: D10.2 (A), SW8.2
unnamed: D11.2 (A), SW9.2
unnamed: D12.2 (A), SW10.2
unnamed: D13.2 (A), SW11.2
unnamed: D14.2 (A), SW12.2
unnamed: D15.2 (A), SW13.2
unnamed: D16.2 (A), SW14.2
unnamed: D17.2 (A), SW15.2
unnamed: D18.2 (A), SW16.2
unnamed: D19.2 (A), SW17.2
unnamed: D20.2 (A), SW18.2
unnamed: D21.2 (A), SW19.2
unnamed: D22.2 (A), SW20.2
unnamed: D23.2 (A), SW21.2
unnamed: D24.2 (A), SW22.2
unnamed: D25.2 (A), SW23.2
unnamed: D26.2 (A), SW24.2
unnamed: D27.2 (A), SW25.2
unnamed: D28.2 (A), SW26.2
unnamed: D29.2 (A), SW27.2
unnamed: D30.2 (A), SW28.2
unnamed: D31.3 (DIN), R18.2
unnamed: D31.1 (DOUT), D36.3 (DIN)
unnamed: D32.3 (DIN), D37.1 (DOUT)
unnamed: D32.1 (DOUT), D33.3 (DIN)
unnamed: D33.1 (DOUT), D38.3 (DIN)
unnamed: D34.3 (DIN), D39.1 (DOUT)
unnamed: D34.1 (DOUT), D35.3 (DIN)
unnamed: D35.1 (DOUT), D40.3 (DIN)
unnamed: D36.1 (DOUT), D41.3 (DIN)
unnamed: D37.3 (DIN), D42.1 (DOUT)
unnamed: D38.1 (DOUT), D43.3 (DIN)
unnamed: D39.3 (DIN), D44.1 (DOUT)
unnamed: D41.1 (DOUT), D45.3 (DIN)
unnamed: D42.3 (DIN), D46.1 (DOUT)
unnamed: D43.1 (DOUT), D47.3 (DIN)
unnamed: D44.3 (DIN), D48.1 (DOUT)
unnamed: D45.1 (DOUT), D49.3 (DIN)
unnamed: D46.3 (DIN), D50.1 (DOUT)
unnamed: D47.1 (DOUT), D51.3 (DIN)
unnamed: D48.3 (DIN), D52.1 (DOUT)
unnamed: D49.1 (DOUT), D53.3 (DIN)
unnamed: D50.3 (DIN), D54.1 (DOUT)
unnamed: D51.1 (DOUT), D55.3 (DIN)
unnamed: D52.3 (DIN), D56.1 (DOUT)
unnamed: D53.1 (DOUT), D54.3 (DIN)
unnamed: D55.1 (DOUT), D56.3 (DIN)
unnamed: D57.2 (A), SW29.S2
unnamed: D62.2 (A), R29.1, R30.1
unnamed: D63.2 (A), SW32.2
unnamed: D64.2 (A), SW33.2
unnamed: D65.2 (A), SW34.2
unnamed: D66.2 (A), SW35.2
unnamed: D67.2 (A), SW36.2
unnamed: D68.2 (A), SW37.2
unnamed: D69.2 (A), SW38.2
unnamed: D70.2 (A), SW39.2
unnamed: D71.2 (A), SW40.2
unnamed: D72.2 (A), SW41.2
unnamed: D73.2 (A), SW42.2
unnamed: D74.2 (A), SW43.2
unnamed: D75.2 (A), SW44.2
unnamed: D76.2 (A), SW45.2
unnamed: D77.2 (A), SW46.2
unnamed: D78.2 (A), SW47.2
unnamed: D79.2 (A), SW48.2
unnamed: D80.2 (A), SW49.2
unnamed: D81.2 (A), SW50.2
unnamed: D82.2 (A), SW51.2
unnamed: D83.2 (A), SW52.2
unnamed: D84.2 (A), SW53.2
unnamed: D85.2 (A), SW54.2
unnamed: D86.2 (A), SW55.2
unnamed: D87.2 (A), SW56.2
unnamed: D88.2 (A), SW57.2
unnamed: D89.3 (DIN), R39.2
unnamed: D89.1 (DOUT), D94.3 (DIN)
unnamed: D90.3 (DIN), D95.1 (DOUT)
unnamed: D90.1 (DOUT), D91.3 (DIN)
unnamed: D91.1 (DOUT), D96.3 (DIN)
unnamed: D92.3 (DIN), D97.1 (DOUT)
unnamed: D92.1 (DOUT), D93.3 (DIN)
unnamed: D93.1 (DOUT), D98.3 (DIN)
unnamed: D94.1 (DOUT), D99.3 (DIN)
unnamed: D100.3 (DIN), D104.1 (DOUT)
unnamed: D95.3 (DIN), D100.1 (DOUT)
unnamed: D96.1 (DOUT), D101.3 (DIN)
unnamed: D101.1 (DOUT), D105.3 (DIN)
unnamed: D102.3 (DIN), D106.1 (DOUT)
unnamed: D97.3 (DIN), D102.1 (DOUT)
unnamed: D99.1 (DOUT), D103.3 (DIN)
unnamed: D103.1 (DOUT), D107.3 (DIN)
unnamed: D104.3 (DIN), D108.1 (DOUT)
unnamed: D105.1 (DOUT), D109.3 (DIN)
unnamed: D106.3 (DIN), D110.1 (DOUT)
unnamed: D107.1 (DOUT), D111.3 (DIN)
unnamed: D108.3 (DIN), D112.1 (DOUT)
unnamed: D109.1 (DOUT), D113.3 (DIN)
unnamed: D110.3 (DIN), D114.1 (DOUT)
unnamed: D111.1 (DOUT), D112.3 (DIN)
unnamed: D113.1 (DOUT), D114.3 (DIN)
unnamed: D115.2 (A), SW58.S2
unnamed: C41.1, Q1.3 (D), R27.1, R28.2, U5.2 (EN/UVLO)
unnamed: Q1.1 (G), R30.2, R42.1
unnamed: R12.2, SW1.1
unnamed: R13.2, SW2.1
unnamed: R17.2, U4.2
unnamed: R18.1, U4.4
unnamed: R33.2, SW30.1
unnamed: R34.2, SW31.1
unnamed: R38.2, U8.2
unnamed: R39.1, U8.4
unnamed: C3.1, R7.1, R8.2, U1.2 (EN/UVLO)
unnamed: R10.2, U1.10 (ILIM)
unnamed: C5.1, U1.1 (dV/dT)
unnamed: SW1.2, U3.26 (RUN)
unnamed: R15.2, U3.51 (USB_DM)
unnamed: R16.2, U3.52 (USB_DP)
unnamed: C19.2, R14.2, U3.46 (VREG_AVDD)
unnamed: L1.2, U3.48 (VREG_LX)
unnamed: C12.2, U3.21 (XIN), Y1.1
unnamed: R11.2, U3.22 (XOUT)
unnamed: SW2.2, U3.60 (~QSPI_SS)
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

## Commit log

2026-05-24 separate left/right part design, schematic
    [backlight.kicad_sch, i2c.kicad_sch, i2c_right.kicad_sch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]
2026-05-24 split definition with duplex UART
2026-05-24 add rotary encoder to firmware
2026-05-24 encoder to schematic
    [encoder.kicad_sch, i2c.kicad_sch, i2c_right.kicad_sch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]
2026-07-11 tray and pcb real estate
    [rp-voyager-tray.step, rp-voyager.FCStd]
2026-07-11 updated pcb to latest tray layout
    [left.kicad_sch, rp_voyager.kicad_pcb]
2026-07-11 JLCDFM check and renders
    [rp_voyager.kicad_pcb]
2026-08-05 make the pcb compatible with kailh choc v1/v2
    [rp_voyager.kicad_pcb, usbc.kicad_sch, usbc_right.kicad_sch]
2026-08-05 flip 5v bulk caps on right panel
    so no traces go on the edges
    [rp_voyager.kicad_pcb]
2026-08-25 fix key switch Kailh Choc v2 compat
    [rp_voyager.kicad_pcb]
2026-08-30 last-last touches before ordering
    [rp_voyager.kicad_pcb]
2026-09-20 encoder pads missing from paste layer
    [rp_voyager.kicad_pcb]
2026-09-20 bom export
    [rp_voyager.csv]
2026-09-20 update case with v1 pcb design
    [rp-voyager.FCStd]
2026-09-24 slight touches on the traces post-1.0
    [rp_voyager.kicad_pcb]
2026-09-26 export board to mechanical design
2026-10-01 match firmware with wiring
2026-10-01 crystal placement, bulk C, wiring updates
    [backlight.kicad_sch, encoder.kicad_sch, key_matrix.kicad_sch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]
2026-10-01 new PCB layout renders
2026-10-02 fixing encoder pins, build for old board
2026-10-03 release v1.1
    [backlight.kicad_sch, encoder.kicad_sch, key_matrix.kicad_sch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]
2026-10-04 PCB: right side layout should match left side
    [board_v12.step, rp-voyager.FCStd, rp_voyager.kicad_pcb]
2026-10-14 use the right encoder
2026-10-24 nice picture of the current stage
2026-10-24 adds optional plate stands, render step and stl
2026-10-24 remove non-final PCB 1.2 export
2026-10-24 tune down LED power to 70% on start
2026-11-03 case stackup, set default plate distance to match KS-33 switches
